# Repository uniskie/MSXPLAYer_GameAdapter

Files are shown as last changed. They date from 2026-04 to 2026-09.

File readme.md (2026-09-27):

# MSXPLAYer Game cartridge Adapter  

[for English](./readme_en.md)

USB CDC（仮想COM）で MSX カセットを読み書きするツールです。（MSXPLAYer対応予定）

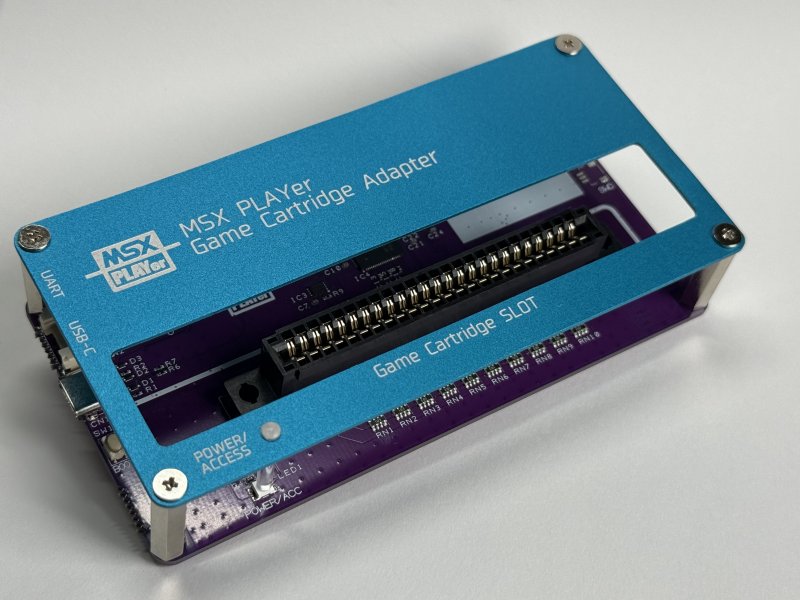
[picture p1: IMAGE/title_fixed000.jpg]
title00


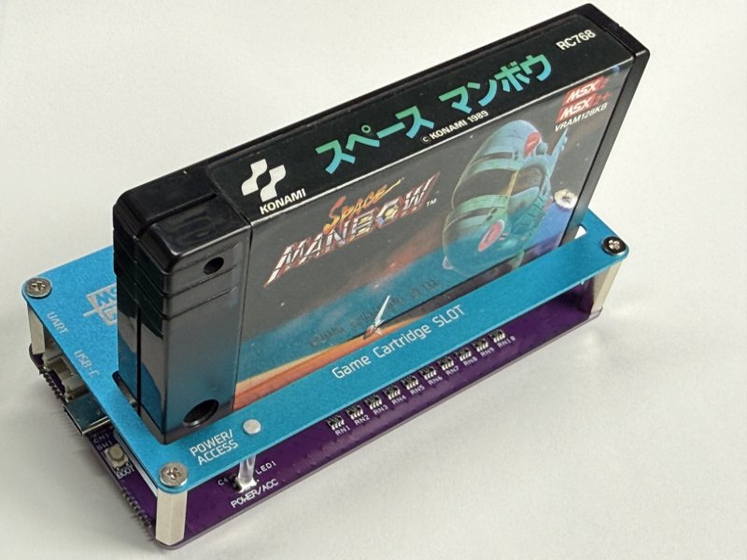
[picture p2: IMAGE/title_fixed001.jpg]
title01


## これは何？

Raspberry Pi 系マイコン（RP2350）を使った **MSX ROM カセット** を読み書きするアダプターです。  
PC から **USB CDC（シリアル）** 経由のコマンドを送ることで下記の事が行えます。

- ROMカセットのRead/Write
- IO Read/Write
- バッファ（64KB）への一括転送、PCへの送受信
- Buffer上の簡易スクリプトによる一括でのスロットアクセス

## 特徴

- **USB CDC（仮想COM）** でコマンド操作（原則ドライバー不要 Windows / Linux / macOS で利用可能）  
- **スロット電源制御・過電流検知機能**を搭載  
- カセットの**メモリおよびIO空間に対するRead/Write**をサポート  
- **クロック信号**をサポート  

- **IO電圧5V対応**
- **ユーザ側での**ファームウェアアップデート可能
- **デュアルコア構成**を活用した低レーテンシー設計  
  - Core0: USB受信・コマンド解析・送信キュー吐き出し  
  - Core1: コマンド実行（GPIOアクセス等）
- **コマンドQueue機能** によりコマンド連続
- **簡易スクリプト**搭載（簡易VM）  

（以下は当方からの頒布品に関して）

- 信頼性が必要なスロットコネクタに **大手メーカ製(AMP/ヒロセ)** 部品を採用

## 実機スロットとの違いについて

実機と異なり下記機能をサポートしていません。  

- +12V/-12Vの電源供給  
- サウンド出力  
- DRAM Refresh信号のサポート  
- M1信号のサポート

## 本体説明

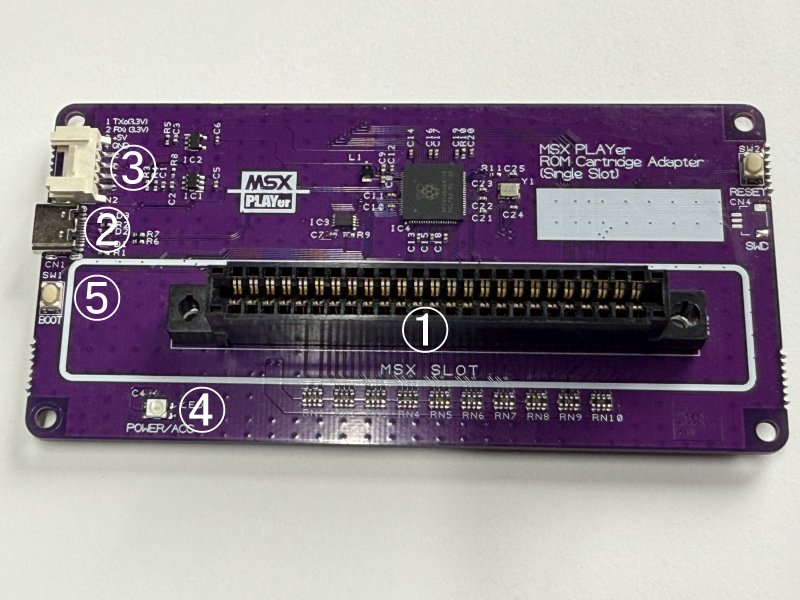
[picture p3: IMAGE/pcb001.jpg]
pcb001


1. MSX SLOT: MSX規格のカセットが挿入します。  
2. USB-C端子: PC本体との接続端子です。  
3. GROVE端子: GROVE仕様の通信端子です。信号の電圧レベルは3.3Vです。現状はデバッグ用のUART信号が出ています。  
4. ACCESS LED: カセットのアクセス状況を示すLEDです。電源供給時およびカセットアクセス時に点灯します。
5. BOOTスイッチ：通常は使用しません。

## [重要] MSXPLAYer対応について

MSXPLAYerの対応は現在、MSX Associationにて進めています。  
当方からの頒布版については、MSXPLAYerが付属予定ですが現段階では未定です。

当面の間は、EarlyAccess版になり、MSXPLAYerを既に持っており、動作チェックに協力いただける、Tester向けの頒布になります。

その為、MSXPLAYerの入手に下記書籍が必要になります。  

**「MSX-BASICでゲームを作ろう　懐かしくて新しいMSXで大人になった今ならわかる」**  
<https://www.amazon.co.jp/dp/4297148900/>
<https://books.rakuten.co.jp/rb/18203653/>  
<https://www.yodobashi.com/product/100000009004112958/>  

こちらで入手したMSXPLAYerにパッチを当てる形で対応を予定しています。  
MSXPLAYer側の不具合発生時の報告用のフォームなども準備中です。  

具体的な対応版入手方法については配布が開始してから追記します。

## OpenMSXなど他プラットフォームの対応について

協力いただける方募集中です。XのDMでご相談いただけると嬉しいです。  

## 頒布について

現在はEarly Access版になります。  
これは、動作チェックや対応ソフトの開発に協力いただける、Tester向けの頒布になります。  
MSXPLAYerは、別途必要になること、将来の正式頒布版と仕様が異なることをご了承できる方のみ購入ください。  

完成させるのには、ドライバーを使った簡単な組み立て作業が必要です。  
コネクターキット版については、スロット部分の簡単な半田付け作業が必要になります。  

### 頒布サイト

スロットが半田付けが必要な半田付けキット版と基板完成版の2種類が用意されます。  
価格については、製造時の世界状況によりしばらくの間大きく変動する可能性が高いです。ご了承ください。  

#### Booth

※2026/5/10 12:00(JPT)～  
<https://ifc.booth.pm/items/8175544>

基板完成版：￥7,060 / 半田付けキット版￥6,560

## 内容物一覧

1. Game cartridge Adapter 基板  
2. 専用アルミパネル  
3. ゴム足
4. スペーサー x 4  
5. ネジ(φ3 x 8mm) x 8  
6. LEDライトパイプ  
7. 50ピンカードエッジコネクタ（半田付けキット版のみ）

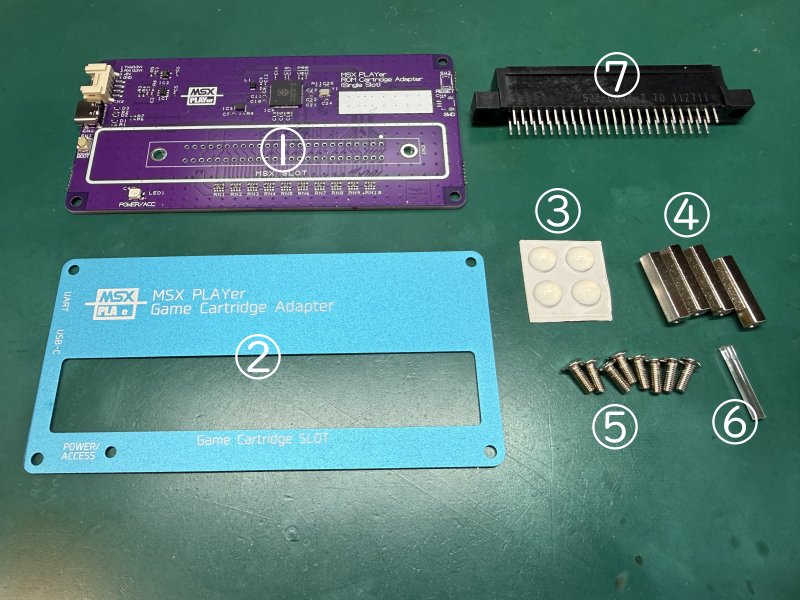
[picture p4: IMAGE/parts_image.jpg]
PARTS


## 組み立て方法

### 1.カードエッジコネクタの半田付け (半田付けキット版のみ)

カードエッジコネクタを半田付けします。コネクタには方向はありません。  
取り付けの際は、基板との隙間が空かない様に注意してください。  
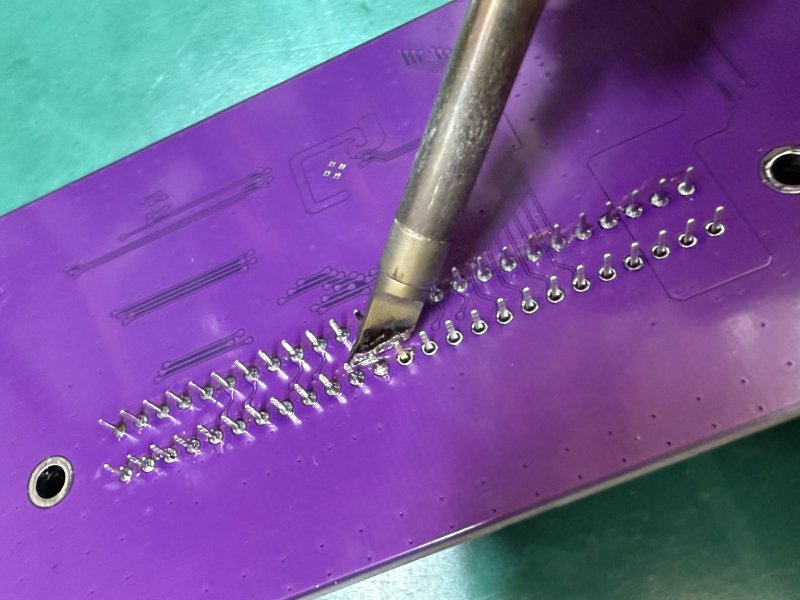
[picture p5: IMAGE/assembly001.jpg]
assembly1


始めに両端の端子を半田付けして浮きが無いか確認してから他の端子を半田付けをすると、確実だと思います。  
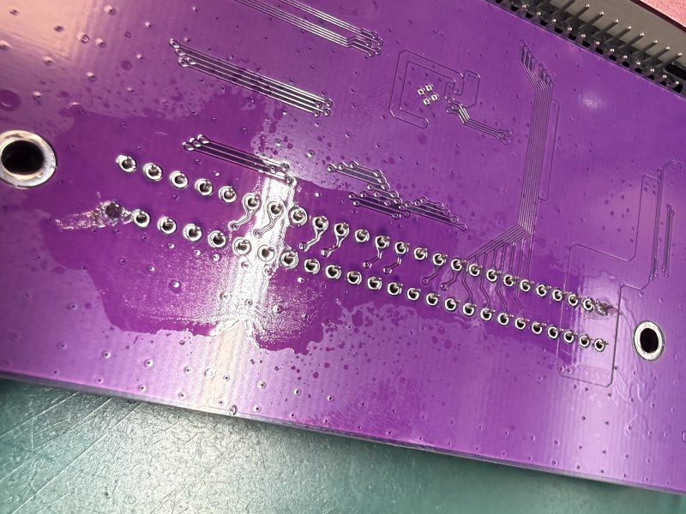
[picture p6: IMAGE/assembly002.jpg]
assembly2


付属のコネクタがヒロセ製の場合、そのままでは少し足が長いので余分な部分はニッパーを使いカットします。  
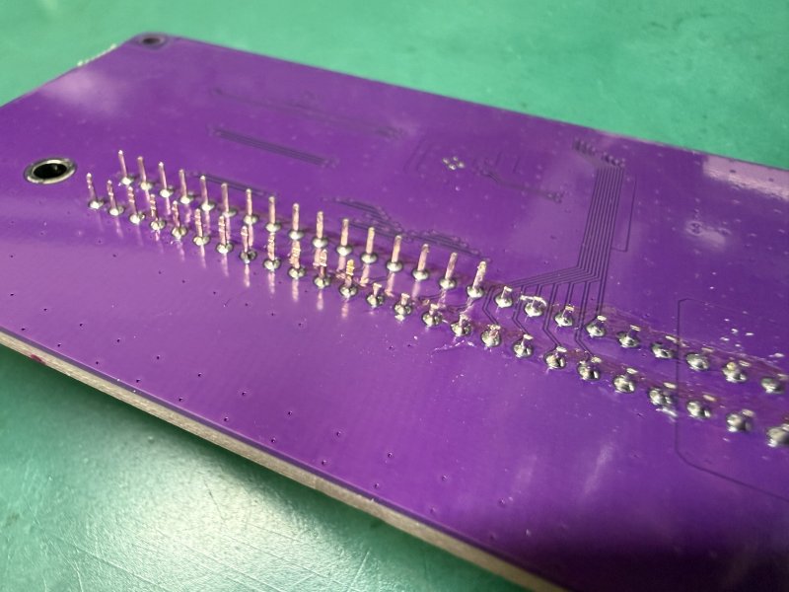
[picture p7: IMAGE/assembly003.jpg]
assembly3


### 2.ライトパイプの取り付け

パネルにライトパイプを押し込みます。平らな面を先にしパネル表面から当該パーツを挿入し、隙間が無くなるまで押し込みます。  
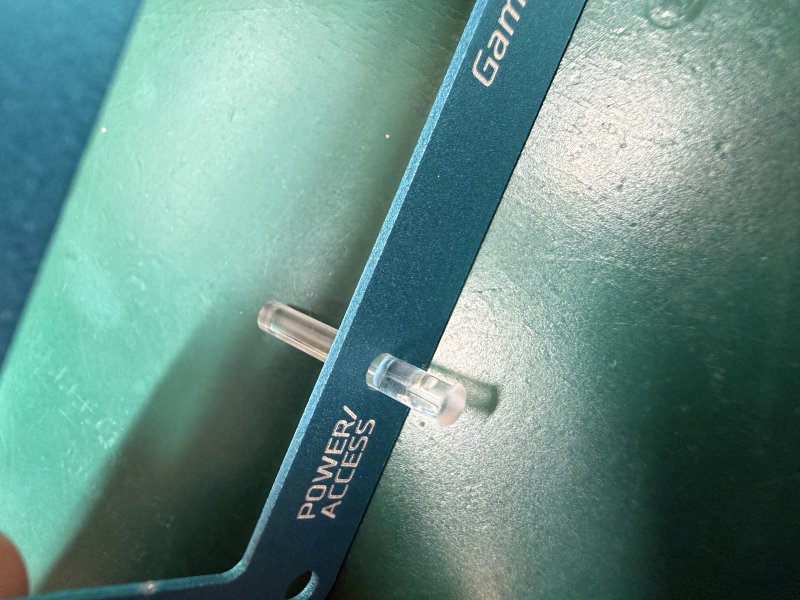
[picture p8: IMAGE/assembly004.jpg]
assembly4

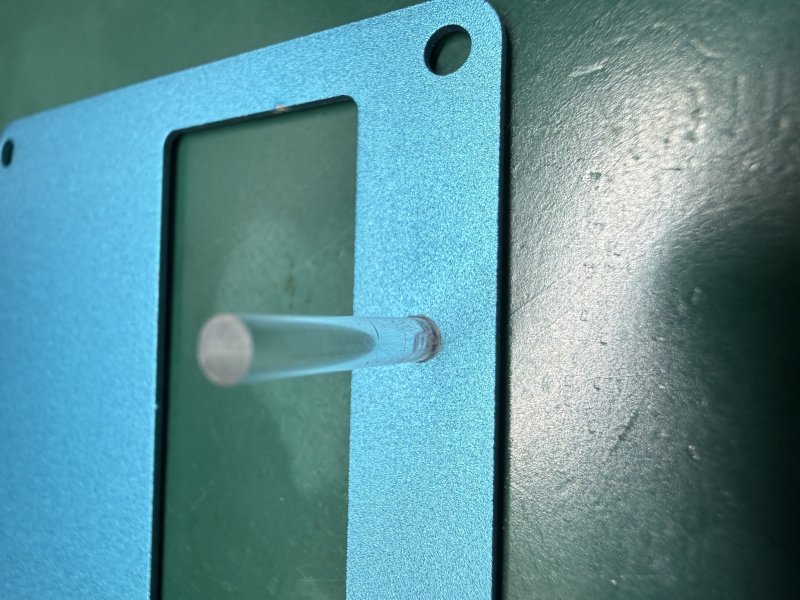
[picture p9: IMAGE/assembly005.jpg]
assembly5


### 3.スペーサーの取り付け(表)

パネル表側をネジ止めしてスペーサを取り付けます。  
最後に微調整をするので、このときは軽く締める程度にして置く方が良いです。  
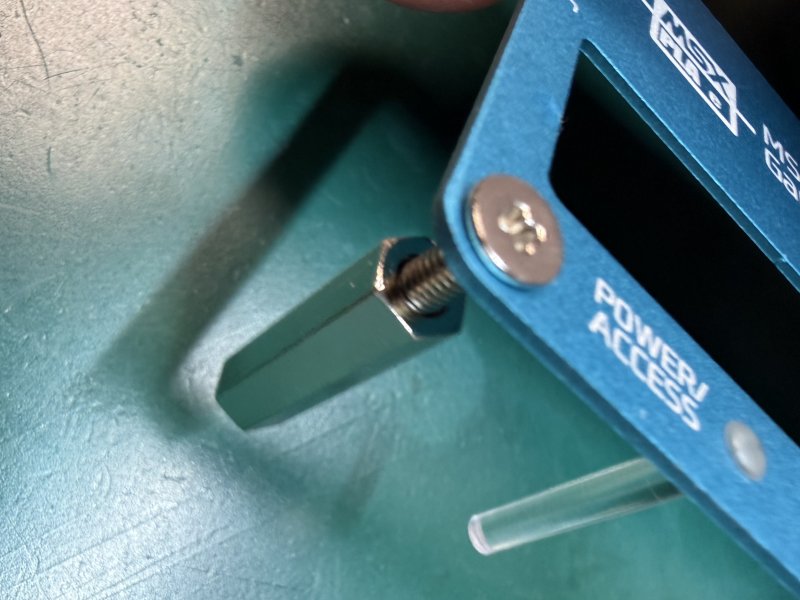
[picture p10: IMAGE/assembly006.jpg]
assembly6


### 4.スペーサーの取り付け(裏)

スペーサの上に基板を載せネジ止めします。基板の向きに注意してください。
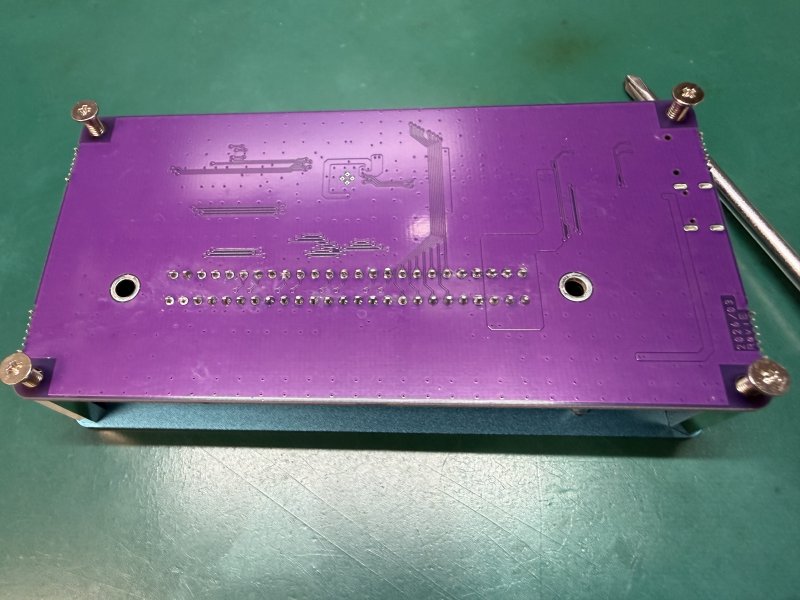
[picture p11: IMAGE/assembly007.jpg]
assembly7

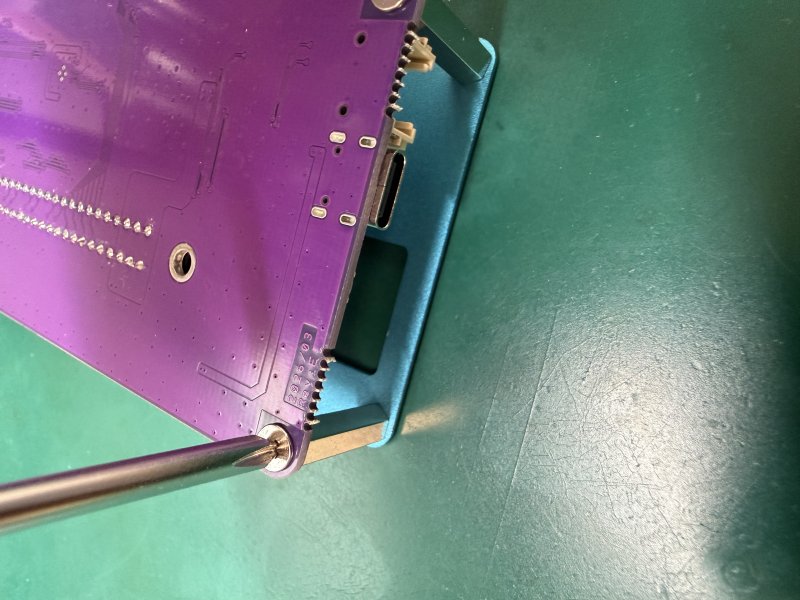
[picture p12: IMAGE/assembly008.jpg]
assembly8


裏面ネジを4本を締めおわったら、表のネジ4本についても本締めしてください。  
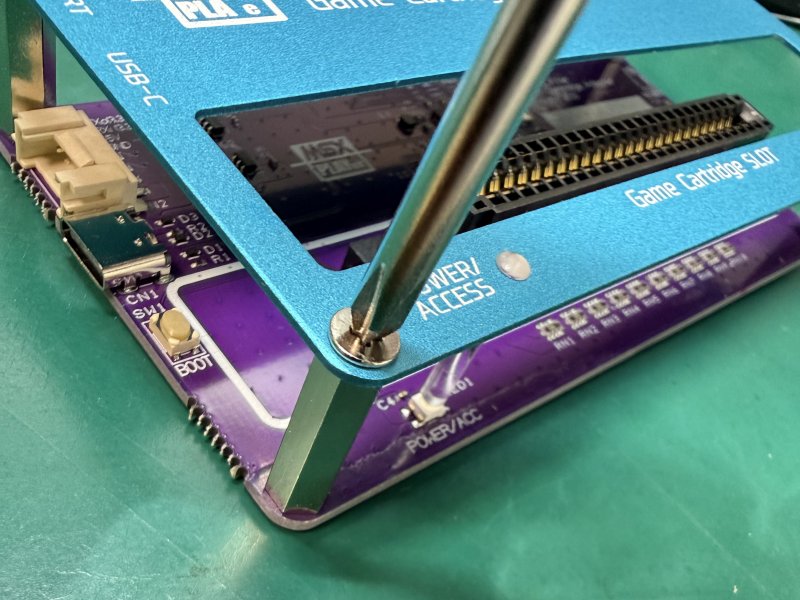
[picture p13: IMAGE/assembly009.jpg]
assembly9


### 5.ゴム足の貼り付け

裏面の基板、ネジ近辺の4カ所にゴム足を貼り付けます。  
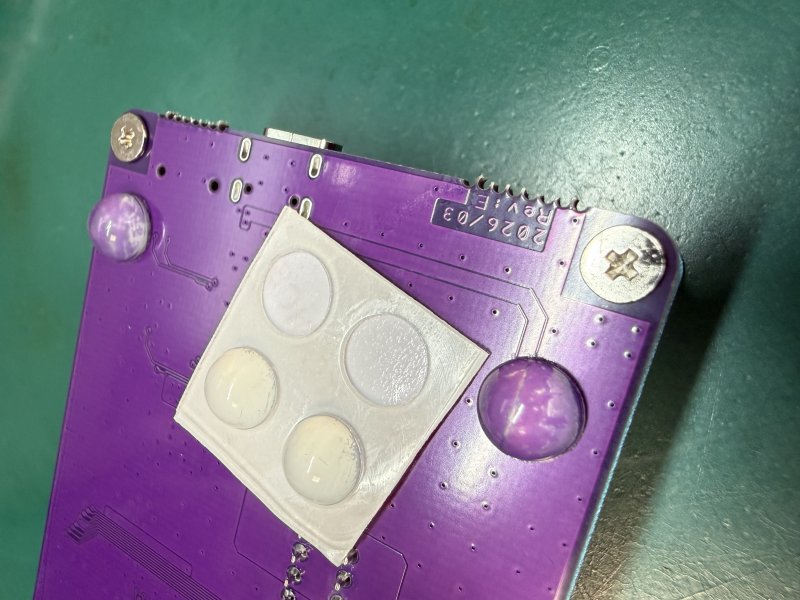
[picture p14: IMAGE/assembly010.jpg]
assembly10


これにてすべての作業が完了です。お疲れ様でした。  

## 動作チェック (Windows向け)  

下記ファイルをダウンロードの上、MSXのカセットを本機に挿して、プログラムを実行してください。  
正常に動作した場合は、下記の様にカセットの0x4000から内容が表示されます。  

**動作チェックプログラム** [MSXPLAYer Game Cassette Adapter動作確認プログラム](./SOFTWARE/TestProgram/)  

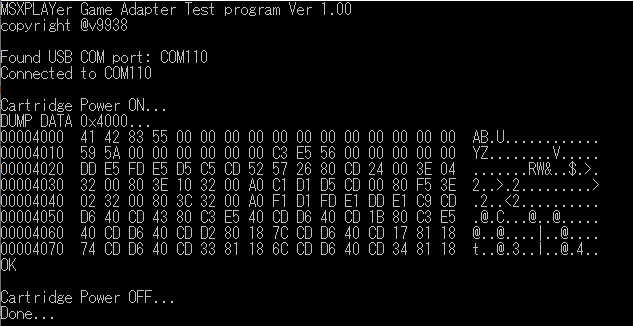
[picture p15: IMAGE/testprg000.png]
動作チェック画面


---

## 技術資料

### USB CDC コマンド仕様

[MSXPLAYer Game Cassette Adapterコマンド仕様](./com_command.md)  

### サンプルプログラム  

Windows向け：(VC++2019/2026で動作確認済)  

- **Game Cartridgeダンプサンプル(要 FW:260531以上):**  [ROMカセットDUMPプログラム](./SOFTWARE/MSXCR_ROMDUMPER_FW260531/)
- **Game Cartridgeダンプサンプル(要 FW:260520以上):**  [ROMカセットDUMPプログラム](./SOFTWARE/MSXCR_ROMDUMPER_FW260519/)
- **Game Cartridgeダンプサンプル:**  [ROMカセットDUMPプログラム](./SOFTWARE/MSXCR_ROMDUMPER/)
- **Script Engineサンプル:** [MSX_SimpleCartridge書き込みプログラム](./SOFTWARE/SimpleROM64KWriter/)  
　　対応cartridge:[https://github.com/v9938/MSX_SimpleCartridge](https://github.com/v9938/MSX_SimpleCartridge)  

### その他プログラム  

- **Litheliaさん作成 MSX-PLAYer-GCA-Reader:**  [https://github.com/Lithelia/MSX-PLAYer-GCA-Reader](https://github.com/Lithelia/MSX-PLAYer-GCA-Reader)  
- **madscientさん作成 mgadump:**  [https://github.com/madscient/mgadump](https://github.com/madscient/mgadump)  
- **t-bucchiさん作成 MSXPLAYer Game Cartidge Adapter GUI:**  [https://github.com/t-bucchi/msx-cartrigde-adapter-gui](https://github.com/t-bucchi/msx-cartrigde-adapter-gui)  

### MSXCR_ROMDUMPER_FW260531 の使い方

本プログラムは FW 260520 以降で追加された `SMTH` コマンドを利用して、
ROM 読み出し時の HASH 値を取得しながらダンプを行う Windows 用ツールです。  
260531版では、バンク処理などを見直して、高速化と動作安定化を図りました。  

#### コマンドライン

- 出力ファイル名を指定する通常モード

  ```bat
  MSXCR_ROMDUMPER.exe dump.rom
  ```

- 出力先ディレクトリを指定する自動ファイル名モード

  ```bat
  MSXCR_ROMDUMPER.exe /AUTO
  ```

  または

  ```bat
  MSXCR_ROMDUMPER.exe /AUTO .\OUT
  ```

#### 各モードの説明

**通常モード**
コマンドライン引数に指定したファイル名で保存します。

**自動ファイル名モード(/AUTO)**
ROM 情報および HASH 値をもとに保存ファイル名を自動決定します。  
第2引数を指定した場合は、そのフォルダーに保存します。  
第2引数を省略した場合はカレントフォルダーに保存します。  

#### msxromdb.xml/softwaredb.xml について

本ソフトは、BlueMSX/OpenMSXのROM Databaseを利用した自動照合を行います。  
'softwaredb.xml' または'msxromdb.xml' のファイル名で実行ファイルと同じフォルダーに配置してください。  
本ファイルが存在する場合、ROM DB 情報を使った名称判定・ファイル名決定に利用されます。  

XML形式のROM DatabaseはBlueMSXのインストールディレクトリーまたは、下記から入手可能です。[https://romdb.vampier.net/downloads.php](https://romdb.vampier.net/downloads.php)  

#### 出力ファイル名について

**通常モード**では、指定したファイル名そのままで保存されます。  
**自動ファイル名モード**では、ROM の判定結果に応じた名前で保存されます。  
`softwaredb.xml`/`msxromdb.xml` が利用できる場合は、ROM DB に登録された情報を優先してファイル名を決定します。  
ROM DB が使えない場合や一致情報が得られない場合は、ROM サイズや HASH 値などを元にした自動生成名になります。  
保存先に同名の既存ファイルがある場合は、そのファイルの内容を読み出して比較します。  
既存ファイルの内容が同一であれば、ファイル名の先頭に `[same_+hash]` を付与します。  
既存ファイルの内容が異なる場合は、ファイル名の先頭に `[other_+hash]` を付与します。  
読み取りに失敗したと推測される場合は、ファイル名の先頭に `[unsuccessful]` を付与します。  

## 動作確認済ROMカセット

[動作確認済ROMカセットリスト](./softlist.md)  

## ファームウェアについて

- Firmware Version: **2.10**
- PCB REV_B2 / REV_Fを起動時に自動判別します。
- USB CDCにはTinyUSB 0.21.0とローカル復旧パッチを使用しています。

下記フォルダーにコンパイル済のファームを置いてあります。  

[ファームウェア置き場](./FIRMWARE/UF2)

## ファームウェアアップデートについて

2種類の方法があります。

- BOOTスイッチを使う方法
BOOTスイッチを押しながら、USBケーブルを挿入してBOOTモードにします。
RP2350の名称のドライブが現れるので上記ファイルをCOPYしてください。  

- Firmware Update用ツールを使う方法  
FFU支援ツールとして`msxcr_ffu.exe`を提供しています。  
上記FFUフォルダーに置いてあるバッチファイル`ffu.bat`を実行するとFirmwareがUpdateされます。  

### ファイル構成（概要）

- `main.c`
  - USB CDC受信（行バッファ → パース）
  - コマンドキュー（Core0→Core1）
  - Slot Memory / IO の Read/Write
  - BRCV受信（バイナリ受信モード）
  - BSND送信（バイナリ送信キュー）
  - LED制御（WS2812）
  - Factory Test（GPIOテスト）
  - Script Engine（executeCommands）
- `commands.c / commands.h`
  - コマンド名 → 実行関数（cmd_*）のテーブル（公開コマンド一覧）
- `ports.c / ports.h`
  - GPIO 定義（`board_pins[]`）
- `ws2812.pio`
  - WS2812制御用PIOプログラム(from SDK pico-examples)
- `pwm_low_hiz.pio`
  - Slot Clock用PIO（LOW→Hi-Z）
- `usb_descriptors.c / tusb_config.h`
  - USB CDCのdescriptor/buffer設定

### ファームウェア動作概要（データフロー）

1. PCからUSB CDCでテキストコマンド送信（例: `SMRD,1000\r\n`）
2. Core0が改行まで `lineBuf` に蓄積し、パースして `commandBufs[]` に投入
3. Core1が `cmd_table[]` から該当関数を探し `cmd_*()` を実行
4. 応答は `cdc_queue[]` に積まれ、Core0の `cdc_task()` がUSBへ送信

### ビルド

Visual Studio CodeのPIC-SDK2.20環境でコンパイルしています。  

## USB VID/PIDについて

MSXライセンスコーポレションの許諾の元 旧ASCII社のVIDとPIDの割り当てを受け使用しています。  
本製品を改変したものを製作する場合は、別のVID/PIDを使用する様にしてください。  

## 回路図  

[回路図 PDF](./PCB/MSXPLAYerCR_1SLOT_RevD.pdf)
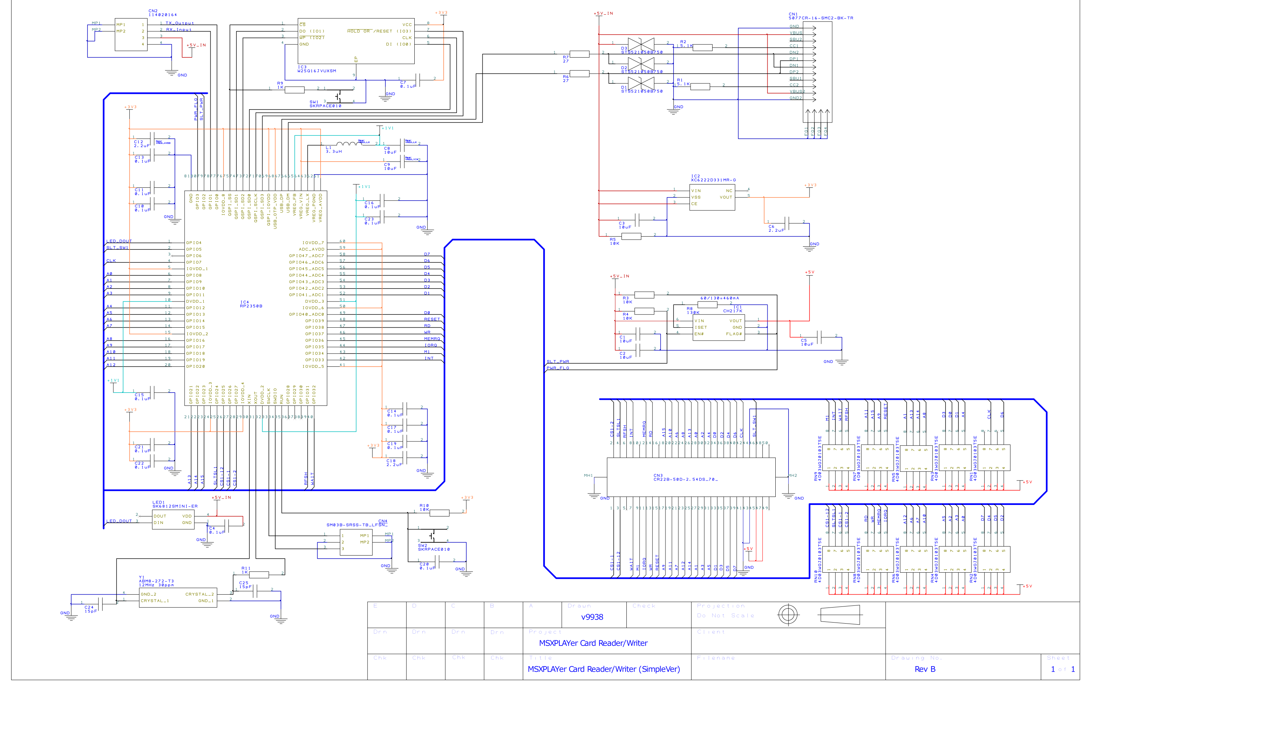
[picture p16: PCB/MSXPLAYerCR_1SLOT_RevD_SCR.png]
回路図


## PCBデータ

[Rev D ガーバデータ](./PCB/GARBER_DATA/)

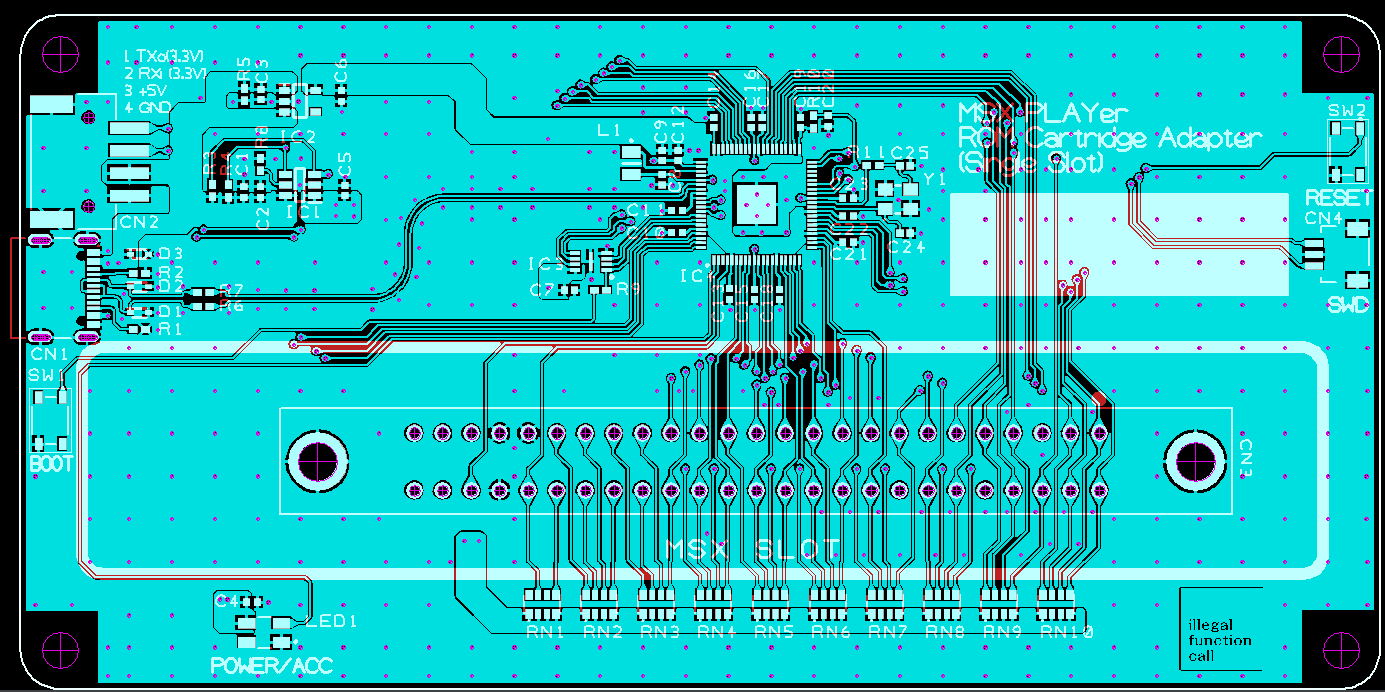
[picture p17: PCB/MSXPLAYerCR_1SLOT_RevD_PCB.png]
PCBイメージ


## BOM List

[Rev D PCBパーツリスト](./PCB/partslist_RevD.md)

## パネル  

[アルミパネルデータ](./PCB/PANEL_DATA/)

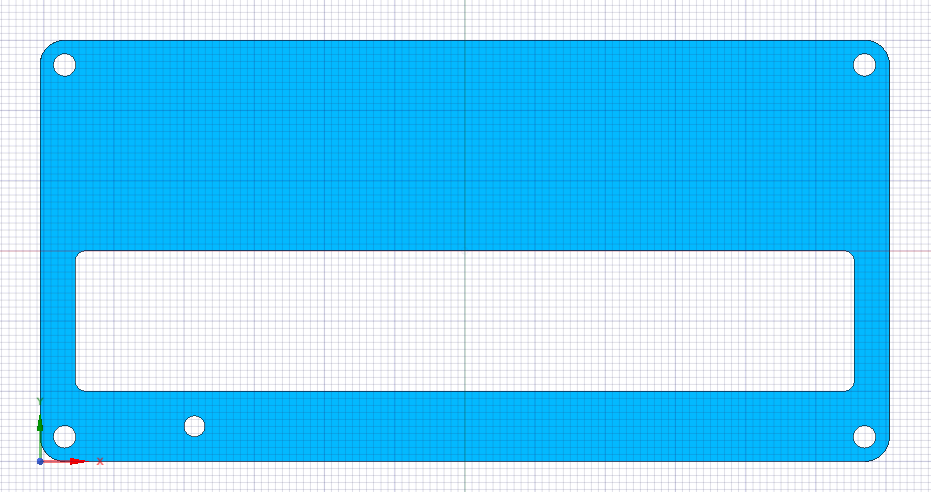
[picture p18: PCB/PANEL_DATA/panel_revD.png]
パネルイメージ


組み立てには、別途下記のパーツが必要です。  

|パーツ名|個数|入手先|
|---|---|---|
|φ3mm x 8mm ネジ|8|<https://www.hirosugi-net.co.jp/shop/g/g104024/>|
|φ3mm x 20mm スペーサー|4|<https://www.hirosugi-net.co.jp/shop/g/g670/>|
|ライトパイプ(VCC LFB075CTP)|1|<https://www.digikey.jp/ja/products/detail/visual-communications-company-vcc/LFB075CTP/5723594>|

## MSXPLAYerの名称／ロゴについて  

MSX および MSXPLAYerはMSXライセンスコーポレションの登録商標です。  

当方の頒布品につけているMSXPLAYerロゴについては、MSXアソシエーションとの開発協力下で当商品への使用が許諾されています。

## ライセンス

このプロジェクトはMIT ライセンスにて公開しています。

なお、コードの一部にRaspberryPiのpico-sdk v2.20よりコピーしたものを含みます。  
当該部分についてはBSD 3-Clause "New" or "Revised" Licenseが定める要件により、Raspberry Pi (Trading) Ltd.よりライセンスされたものです。

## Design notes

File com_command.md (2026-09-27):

# MSXPLAYer Game Cassette Adapterコマンド仕様  

## 共通仕様

- 1行 = 1コマンド（`,`区切り）
- フォーマット（最大4引数）:

  ```CMD
  CMD[,ARG1[,ARG2[,ARG3[,ARG4]]]]<CR|LF|CRLF|LFCR>
  ```

- コマンド名は大文字小文字を区別しません（内部で大文字化）
- 引数は基本 **16進数**（`0x` プレフィクス可）
- 未指定引数は、デフォルト動作になります。
- 戻り値:
  - 通常は処理結果として最後に `OK` / `FAIL` を返します
  - `ERROFF` 中は OK/FAIL 表示を抑止し、成功/失敗カウントのみ更新します

## コマンド一覧（仕様書形式・実装準拠）

### 1) HSET - Hardware Setting

- **機能**: ハードウェアアクセス時の待ち時間や互換モードを設定する
- **書式**: `HSET,[Address],[Data]`
- **引数**:
  - `Address` : 設定項目番号（16進）
  - `Data` : 設定値（16進、省略時は初期値に戻す）
- **応答**: `OK` / `FAIL`
- **備考**:
  - 現在のファームでは下記設定に対応しています。

| Address | 設定項目 | 内容 | 初期値 |
|---|---|---|---|
| `0` | `MEMWAIT` | Memory Read/Write後のWait時間 (`n x 10ns`) | `0` |
| `1` | `RDWAIT` | Memory Read時の/RD信号幅 (`n x 10ns`) | `100` |
| `2` | `WRWAIT` | Memory Write時の/WR信号幅 (`n x 10ns`) | `18` |
| `3` | `P6MODE` | PC-6001 16KB mode設定 (`0`:OFF / `1`以上:ON) | `0` |

- **設定例**:
  - `HSET,1,64` : RDWAIT を `1000ns=1us` に設定
  - `HSET,1` : RDWAIT を初期値に戻す

- **補足**:
  - 設定値は `HINF` コマンドで確認できます。
  - `HINF` の出力には `MEMWAIT` / `RDWAIT` / `WRWAIT` / `P6MODDE` が表示されます。
  - 未対応の `Address` を指定した場合は `FAIL` になります。

---

### 2) ERROFF - Result display OFF

- **機能**: コマンド実行結果の逐次表示（OK/FAIL表示）を抑止する
- **書式**: `ERROFF`
- **引数**: なし
- **応答**: `OK`
- **備考**:
  - 有効時は `passCount/errCount` で統計を蓄積
  - 大量処理（転送・スクリプト）時のログ抑制に利用

---

### 3) ERRON - Result display ON + summary

- **機能**: `ERROFF` を解除し、抑止期間の集計を表示する
- **書式**: `ERRON`
- **引数**: なし
- **応答**:
  - `PASS : <passCount>`
  - `FAIL : <errCount>`
  - その後、失敗があれば `FAIL`、なければ `OK`
- **備考**:
  - `FAIL` があった場合は `ERRON` 自体が `FAIL` で返る仕様

---

### 4) BCLR - Buffer Clear（slotMem 初期化）

- **機能**: 内部バッファ（64KB）を指定値で埋める
- **書式**: `BCLR(,[BufferAddress],[Length],[Data])`
- **引数**:
  - `BufferAddress` : 開始位置（省略時 0）
  - `Length` : 長さ（省略時 64KB相当）
  - `Data` : 埋め値（省略時 `0xFF`）
- **応答**: `OK` / `FAIL`
- **備考**:
  - 範囲外指定は `FAIL`
  - 長さはバッファ境界に合わせて補正される場合がある

---

### 5) BSND - Buffer Send Host（Device→Host バイナリ送信）

- **機能**: 内部バッファのデータをPCへ送信する（バイナリ）
- **書式**: `BSND,[BufferAddress],[Length]`
- **引数**:
  - `BufferAddress` : 送信開始位置
  - `Length` : 送信バイト数
- **応答**:
  - バイナリデータがPCに送信されます。
  - その後に `OK/FAIL`（displayFlag=true時）が送信されます。
- **備考**:

---

### 6) BRCV - Buffer Receive Host（Host → Device バイナリ受信）

- **機能**: PCから指定長のバイナリを受信し、`slotMem[]` に格納する
- **書式**: `BRCV,[BufferAddress],[Length]` +（続けて Length バイトのバイナリ本体）
- **引数**:
  - `BufferAddress` : 格納開始位置
  - `Length` : 受信バイト数
- **応答**:
  - 受信完了後に `OK/FAIL`
- **備考**:
  - `BRCV` 実行後直後はバイナリ受信モードへ移行します
  - 範囲外（`BufferAddress + Length` が64KB超）などは `FAIL`
  - コマンド終端には `CR` / `LF` / `CRLF` / `LFCR` を使用できます。

---

### 7) HVER - Hardware Version

- **機能**: ハードウェア名、PCBリビジョン、ファームウェアバージョンを表示
- **書式**: `HVER`
- **引数**: なし
- **応答**:
  - `HARDWARE NAME : <Hardware Name>`
  - `HARDWARE VER : <REV_B2|REV_F|UNKNOWN>`
  - `FIRMWARE VER : <Firmware Version>`
  - `OK`
- **備考**:
  - PCB REV_B2/REV_Fは起動時に自動判別します。
  - 判定できない場合は`UNKNOWN`を表示します。
  ※ 260531(V1.40)で出力フォーマットが変更になっています。  

---

### 8) HINF - Hardware Information

- **機能**: ハード構成情報の表示
- **書式**: `HINF`
- **引数**: なし
- **応答**: 各種 `KEY,VALUE` 行 + `OK`
- **備考**:
  - `SLOTNUM`: Readerのスロット数  
    Readerについている物理スロット数を表します(1～4)
  - `SLOTPHY`: Readerの物理スロット配置情報  
    Readerについている物理スロットの配置を示します。(1が有効)

    |bit7-4|bit3|bit2|bit1|bit0|
    |---|---|---|---|---|
    |0000|SLOT3|SLOT2|SLOT1|SLOT0|

    例：SLOTNUM:1 / SLOTPHY:2 = 付いているスロット1つでSLOT1扱い  

  - `POWERCTRL`: 電源制御有無  
    カセットに対する電源制御の有無を示します。(1で有り)  
  - `CURRENTSENSOR`: 過電流制御有無  
    カセットに対する過電流検知回路の有無を示します。(1で有り)  
  - `PWR12V`: +12V/-12V電源の有無  
    カセットに対する+12V/-12Vの有無を示します。(1で有り)  
  - `SLOTCLOCK`: 外部スロットクロックの有無  
    カセットに対する精密な3.58MHzのクロック供給回路の有無を示します。(1で有り)  
  - `LINEOUT`: 音声LineOut有無  
    カセットのSOUND端子の出力回路の有無を示します。(1で有り)  
  - `PSGUNIT`: PSG ユニット有無  
    ReaderにPSG音源相当相当の機能があるか示します。(1で有り)  
  - `LFCR`: 改行コードの設定値  
    入力されているCOMMAND文字列の改行コードの種別を表示しています。(1は、"\n" = 0x0d,0x0a 扱い)  
  - `COMDBG`: UARTからのデバッグ出力設定値  
    1の時はUARTからデバッグ用の出力が出る設定です。  
  - `SCRLOOP`: ScriptモードのLOOP回数の最大設定値  
    ScriptモードのLOOP回数を表示します。初期値は1000回  
  - `MEMWAIT`: Read/Write後のWait値  
    Memory Read/Write後のWait時間 初期値は0  
  - `RDWAIT`: Memory Read時の/RD幅  
    Memory Readの/RDがLOWになっている時間の設定値 初期値は10 (180ns)  
  - `WRWAIT`: Memory Write時の/WR幅  
    Memory Writeの/WRがLOWになっている時間の設定値 初期値は10 (180ns)  
  - `P6MODE`: PC6001カセットモードの設定値  
    PC6001 16K Read Modeの設定値表示  

---

### 9) HSTS - Hardware Internal Status

- **機能**: 内部状態（主にキュー残数・エラー有無）の表示
- **書式**: `HSTS`
- **引数**: なし
- **応答**:
  - キュー残数相当（`count-1`）を1行表示
  - `OK/FAIL`
- **備考**:
  - 実行したキューにエラーが発生した場合は`FAIL`になります。  

---

### 10) SCHK - Slot Cassette Check

- **機能**: スロット接続状態を表示（Power ON不要）
- **書式**: `SCHK`
- **引数**: なし
- **応答**: `0000/0010/0100/0110` のいずれか + `OK`
- **備考**: 応答値はSLOT3210の順番の文字列です。カセットがさしてあるスロットが1になります。  

---

### 11) SPON - Slot Power ON

- **機能**: スロット電源投入、クロック有効化、RESET制御等の初期化
- **書式**: `SPON`
- **引数**: なし
- **応答**: `OK/FAIL`
- **備考**:
  - 過電流発生時は `FAIL`になります。  

---

### 12) SPOFF - Slot Power OFF

- **機能**: スロット電源断、信号を安全状態へ戻す
- **書式**: `SPOFF`
- **引数**: なし
- **応答**: `OK/FAIL`
- **備考**:

---

### 13) SRST - Slot Reset

- **機能**: スロットRESET信号をトグルしてリセットする
- **書式**: `SRST`
- **引数**: なし
- **応答**: `OK`

---

### 14) SSEL - Slot Select

- **機能**: デフォルトスロット番号を設定
- **書式**: `SSEL,[Slot]`
- **引数**:
  - `Slot` : `1` または `2`
- **応答**: `OK/FAIL`
- **備考**:
  - `Slot` 未指定は `FAIL`
  - 以後、Slot省略時にこの値が使われる

---

### 15) SMRD - Slot Memory Read（1 byte）

- **機能**: スロットメモリから1バイト読み出す
- **書式**: `SMRD,[Address](,[Slot])`
- **引数**:
  - `Address` : 0000〜FFFF　スロットメモリアドレス
  - `Slot` : 1 or 2（省略時はdefaultSlot）
- **応答**:
  - `<addr> : <data>`（例 `1000 : 3F`）+ `OK/FAIL`

---

### 16) SMWR - Slot Memory Write（1 byte）

- **機能**: スロットメモリへ1バイト書き込む
- **書式**: `SMWR,[Address],[Data](,[Slot])`
- **引数**:
  - `Address` : 0000〜FFFF　スロットメモリアドレス  
  - `Data` : 00〜FF　書き込みデータ  
  - `Slot` : 1 or 2（省略時defaultSlot）
- **応答**: `OK/FAIL`

---

### 17) SMTR - Slot → Buffer Transfer Read（一括Read）

- **機能**: スロットからバッファーへ連続読み出し
- **書式**: `SMTR,[Address](,[Length],[BufferAddress],[Slot])`
- **引数**:
  - `Address` : 0000〜FFFF　スロット側開始アドレス
  - `Length` :  0000〜FFFF　読み込み長（省略時最大）
  - `BufferAddress` :  0000〜FFFF　バッファー格納開始位置（省略時0）
  - `Slot` : 1 or 2（省略時defaultSlot）
- **応答**: Data + `OK/FAIL`

---

### 18) SMTW - Buffer → Slot Transfer Write（一括Write）

- **機能**: バッファーからスロットへ連続書き込み
- **書式**: `SMTW,[Address],[Length],[BufferAddress](,[Slot])`
- **引数**:
  - `Address` :  0000〜FFFF　スロット側開始アドレス
  - `Length` :  0000〜FFFF　書き込み長
  - `BufferAddress` : バッファー 読み出し開始位置
  - `Slot` : 1 or 2（省略時defaultSlot）
- **応答**: `OK/FAIL`

---

### 19) IORD - IO Read（1 byte）

- **機能**: IOポートから1バイト読み出す
- **書式**: `IORD,[IO]`
- **引数**:
  - `IO` :  0000〜FFFF　IOアドレス（16bit扱い）
- **応答**:
  - `<io> : <data>` + `OK/FAIL`

---

### 20) IOWR - IO Write（1 byte）

- **機能**: IOポートへ1バイト書き込む
- **書式**: `IOWR,[IO],[Data]`
- **引数**:
  - `IO` :  0000〜FFFF　IOアドレス  
  - `Data` : 00〜FF　書き込みデータ  
- **応答**: `OK/FAIL`

---

### 21) IOTR - IO → Buffer Transfer Read（実装準拠）

- **機能**: IOから連続読み出ししてバッファーへ格納
- **書式**: `IOTR,[IO],[Length],[BufferAddress](,[Mode])`
- **引数（実装準拠）**:
  - `IO` : 0000〜FFFF　開始IOアドレス
  - `Length` :0000〜FFFF　読み出し回数（バイト数）
  - `BufferAddress` : バッファー格納開始位置
  - `Mode` : 1 でIOアドレスはアクセス毎に加算、省略時は同一アドレスにアクセス (機能追加：V1.41～)
- **応答**: `OK/FAIL`

---

### 22) IOTW - Buffer → IO Transfer Write（実装準拠）

- **機能**: バッファーからIOへ連続書き込み
- **書式**: `IOTW,[IO],[Length],[BufferAddress](,[Mode])`
- **引数（実装準拠）**:
  - `IO` : 0000〜FFFF　開始IOアドレス
  - `Length` : 0000〜FFFF　書き込み回数（バイト数）
  - `BufferAddress` : 0000〜FFFF　バッファー読み出し開始位置
  - `Mode` : 1 でIOアドレスはアクセス毎に加算、省略時は同一アドレスにアクセス (機能追加：V1.41～)
- **応答**: `OK/FAIL`

---

### 23) BDMP - Buffer Dump（デバッグ用）

- **機能**: バッファーの内容を HEX+ASCII で表示
- **書式**: `BDMP,[BufferAddress](,[Length])`
- **引数**:
  - `BufferAddress` : 0000〜FFFF　開始位置（省略時0）
  - `Length` : 0000〜FFFF　表示長（省略時128）
- **応答**: ダンプ行 + `OK`

---

### 24) SDMP - Slot Dump（スロットメモリダンプ）

- **機能**: スロットから直接読みながらダンプ表示
- **書式**: `SDMP,[Address](,[Length],[Slot])`
- **引数**:
  - `Address` : 0000〜FFFF　開始アドレス（省略時0）
  - `Length` : 0000〜FFFF　表示長（省略時128）
  - `Slot` : 1 or 2（省略時defaultSlot）
- **応答**: ダンプ行 + `OK/FAIL`

---

### 25) BSCR - Buffer Script Execute（スクリプト実行）

- **機能**: バッファー上のスクリプトを実行する
- **書式**: `BSCR,[BufferAddress](,[Slot])`
- **引数**:
  - `BufferAddress` :  0000〜FFFF　スクリプト先頭（省略時0）
  - `Slot` : 1 or 2（省略時defaultSlot）
- **応答**: `OK/FAIL`
- **備考**:
  - 命令形式は 4byte/命令: `[cmd][addr_hi][addr_lo][data]`
  - スクリプトの詳細は別章を参照

---

### 26) FTEST - Factory Test

- **機能**: 工場向け総合テストの実行
- **書式**: `FTEST`
- **引数**: なし
- **応答**: テストログ + `OK/FAIL`

---

### 27) LEDRDY / LEDPON / LEDACC - LED色設定

- **機能**: LED色（READY/POWER ON/SLOT ACCESS）を RGB で設定
- **書式**:
  - `LEDRDY(,[R],[G],[B])`
  - `LEDPON(,[R],[G],[B])`
  - `LEDACC(,[R],[G],[B])`
- **引数**:
  - `R` `G` `B` : 0x00〜0xFF（省略可。省略時はデフォルト値）
- **応答**: `OK`

---

### 28) SDBGON - Serial Debug Log ON

- **機能**: シリアルポートからのデバッグログ出力を有効化
- **書式**: `SDBGON`
- **引数**: なし
- **応答**: `OK`
- **備考**:
  - シリアル出力が増える分実行速度が低下します。
  - バッファーオーバーフローに注意してください。  
  - シリアルはGrove端子より出力されます。

---

### 29) _FFU - Bootloader起動

- **機能**: FFUモードへの移行、USBブートモードへ移行する
- **書式**: `_FFU`
- **引数**: なし
- **応答**: メッセージ出力後、リブート（以降のOK/FAILは返さない）

---

### 30) LSCR - ScriptモードのLOOP回数の最大値設定

- **機能**: Scriptモードの条件成立待ちのループ回数を設定します。  
- **書式**: `LSCR(,最大LOOP回数)`
- **引数**: 0-0xFFFF (省略時は初期値の1000回)
- **応答**: `OK`

---

[260520_VERにて追加]

### 31) SMTH - Slot → Buffer Transfer Read（一括Read）+ HASH

- **機能**: スロットからバッファーへ連続読み出し+ 32bit HASHコードを計算します。  
- **書式**: `SMTH,[Address](,[Length],[BufferAddress],[Slot])`
- **引数**:
  - `Address` : 0000〜FFFF　スロット側開始アドレス
  - `Length` :  0000〜FFFF　読み込み長（省略時最大）
  - `BufferAddress` :  0000〜FFFF　バッファー格納開始位置（省略時0）
  - `Slot` : 1 or 2（省略時defaultSlot）
- **応答**: `<Length> : <HASH 32bit>`+`OK/FAIL`

---

[260531_VERにて追加]

### 32) RMSET - ROM Mapper Setting

- **機能**: RMRDコマンドで使うParameterをセットします。  
- **書式**: `RMSET,[Mapper Selector Address],[Bank Read Address],[Bank size]`
- **引数**:
  - `Mapper Selector Address]` : 0000〜FFFF　ROM Mapperの切り替えアドレス、FFFFを指定した場合は、バンク切り替えをしません。  
  - `Bank Read Address` :  0000〜FFFF　ReadするBankの先頭アドレス  
  - `Bank size` :  0000〜FFFF　1バンク辺りの容量
- **応答**: `OK/FAIL`

---

### 33) RMRD - ROM Mapper Read

- **機能**: スロットに挿してあるメガロムをバンクを切り替えながら一括で読み込みます。(バッファーは使用しません)  
- **書式**: `RMRD,[Start Bank],[Bank Capacity](,[Slot])`
- **引数**:
  - `Start Bank` : 00〜FF　スロット側開始アドレス
  - `Bank Capacity` :  00〜FF　読み込むBANK数を指定します  
  - `Slot` : 1 or 2（省略時defaultSlot）
- **応答**: Read Data + `OK/FAIL`

---

### 34) SMMR - Slot M1 Read

- **機能**: M1サイクルを使用してスロットメモリから1バイト読み出す
- **書式**: `SMMR,[Address](,[Slot])`
- **引数**:
  - `Address` : 0000〜FFFF 読み出しアドレス
  - `Slot` : 1 または 2（省略時はdefaultSlot）
- **応答**: `<Address> : <Data>` + `OK/FAIL`

---

### 35) MDMP - Slot M1 Dump

- **機能**: M1サイクルを使用してスロットメモリを読み出し、HEXおよびASCII形式で表示する
- **書式**: `MDMP,[Address](,[Length],[Slot])`
- **引数**:
  - `Address` : 0000〜FFFF 読み出し開始アドレス（省略時0000）
  - `Length` : 表示バイト数（省略時0080）
  - `Slot` : 1 または 2（省略時はdefaultSlot）
- **応答**: 16バイト単位のHEX/ASCIIダンプ + `OK/FAIL`

---

## シリアルコマンド例

### 例1: スロットの0x0000〜0x3FFFを読み出してPCへ送信

```CMD_EX1
SPON
SMTR,0000,4000,0000,01
BSND,0000,4000
SPOFF
```

### 例2: PCからバイナリを受信し、0x8000へ書き込み

```CMD_EX2
SPON
BRCV,0000,2000
(ここで 0x2000 バイトのバイナリを送信)
SMTW,8000,2000,0000,01
SPOFF
```

[260531_VERにて追加]

### 例3: ASCII8K Typeの1Mbitメガロムカセットを一括で読み込む

```CMD_EX3
SPON
RMSET,7000,8000,2000
RMRD,0,10
(ここで 0x20000 バイトのバイナリを受信)
SPOFF
```

## スクリプトモードについて

バッファーにおいたスクリプトを使うことで、PCとの通信をしないで、
データRead/Write・比較の実行を行うことが出来るモードです。  

## スクリプト形式

- スクリプト形式: [Command],[Address(2Byte)],[DATA]...  
- 1スクリプトは4バイトの固定長です。  

### スクリプトデータ フォーマット

|Address|＋0Byte|＋1Byte|＋2Byte|＋3Byte|
|---|---|---|---|---|
|**DATA**|命令コード|上位アドレス|下位アドレス|データ|

### 命令一覧

|Command|命令名|説明|
|---|---|---|
|0x00|NOP|何もしない|
|0x01|Read Memory|Slotに対してReadを実行|
|0x02|Write Memory|Slotに対してDATAを書き込む (LastDataはDATAで上書きされます)|
|0x03|Read IO|Slotに対してIOを使ったReadを実行します。(LastDataはReadしたDATAになります)|
|0x04|Write IO|Slotに対してIOを使ったWriteを実行します。(LastDataはDATAで上書きされます)|
|0x05|Wait|addressで指定したms時間待機します|
|0x06|Compare|LastDataとdataを比較します、一致したら次の命令はスキップします。|
|0x07|AND|LastData [AND] DATAを計算します、結果が0x00なら次の命令をスキップします。|
|0x08|OR|LastData [OR] DATAを計算します、結果が0x00なら次の命令をスキップします。|
|0x09|XOR|lastData [XOR] DATAを計算します、結果が0x00なら次の命令をスキップします。|
|0x0A|JMP|DATAの値だけ命令をスキップします。（0x00-7F=先命令/0x80-FF=前命令）|
|0x0B|PUSH|lastDataをaddressで指定した位置のBufferメモリに書き出します |
|0xFE|Abort|スクリプト実行を失敗で終了|
|0xFF|End|スクリプト実行を成功で終了|

※ JMP命令は、一定回数(初期値は1000回)同じ場所で実行されるとスクリプト失敗になります。  
当該値は"LSCR"コマンドで変更可能です。  

### スクリプト例

下記のコマンドで実行可能です。

```CMD_BRCV
BRCV,0,20  
(下記バイナリー送付)  
BSCR,0
```

|バイナリー値|Command|説明|
|---|---|---|
|0x02,0x55,0x55,0xaa|[Write Memory]  Address:0x5555 Data:0xaa|0x5555に0xAAの書き込み|
|0x02,0xaa,0xaa,0x55|[Write Memory]  Address:0xaaaa Data:0x55|0xAAAAに0x55の書き込み|
|0x02,0x55,0x55,0xa0|[Write Memory]  Address:0x5555 Data:0xa0|0x5555に0xA0の書き込み|
|0x02,0x40,0x00,0x41|[Write Memory]  Address:0x4000 Data:0x41|0x4000に0x41の書き込み|
|0x01,0x40,0x00,0x00|[Read Memory]  Address:0x4000|0x4000のデータを読み込む|
|0x06,0x00,0x00,0x41|[Compare]  Data:0x40|先ほど読み込んだデータと比較して0x40だったら次の命令はスキップ|
|0x0a,0x00,0x00,0xfe|[JMP] -2|2つ前の命令に戻る(つまり、0x4000が0x40になるまでループする)|
|0xff,0x00,0x00,0x00|End|スクリプト終了|

## デバッグについて

"SDBGON"コマンドを実行する事でGROVE端子(UART)より実行ログを取得できます。  
ただし、当該機能を有効にすると実行時間が遅くなりますので通常は有効にしないでください。  

シリアルポートは3.3Vレベルで配線は下記の様になっています。  
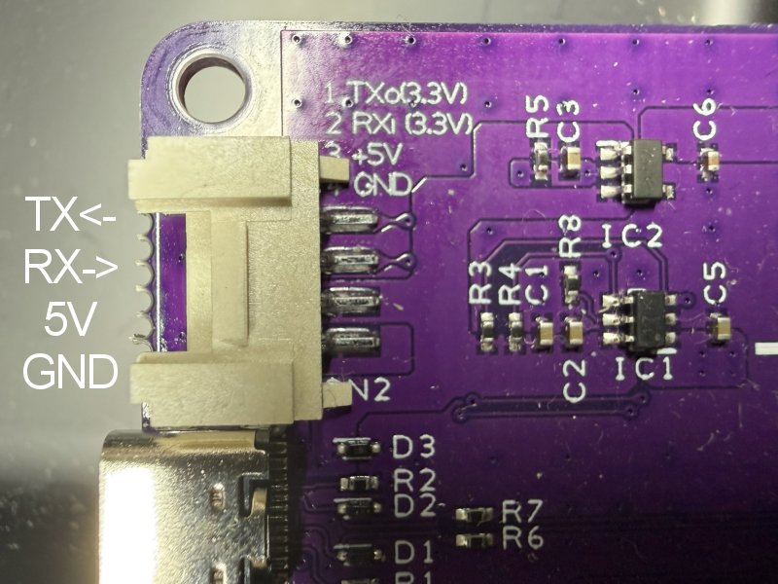
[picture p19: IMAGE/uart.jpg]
UART


### 出力例

```CMD_DEBUGOUT
BRCV_OK20
SKIP : 0a
BIN End
BSCR,0
0: Write Memory 5555:aa
4: Write Memory 2aaa:55
8: Write Memory 5555:a0
12: Write Memory 4000:41
16: Read Memory 4000:ff
20: Compare ff=41
24: JMP
16: Read Memory 4000:ff
20: Compare ff=41
24: JMP
16: Read Memory 4000:ff
20: Compare ff=41
24: JMP
16: Read Memory 4000:ff
20: Compare ff=41
24: JMP
16: Read Memory 4000:41
20: Compare 41=41
28: End Script(PASS)
```CMD_BRCV

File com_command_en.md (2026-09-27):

# MSXPLAYer Game Cassette Adapter Command Specifications

## General Specifications

- 1 line = 1 command (comma-separated)
- Format (maximum 4 arguments):

  ```CMD
  CMD[,ARG1[,ARG2[,ARG3[,ARG4]]]]<CR|LF|CRLF|LFCR>
  ```

- Command names are case-insensitive (converted to uppercase internally)
- Arguments are basically **hexadecimal** (`0x` prefix is allowed)
- If an argument is omitted, the default behavior is used.
- Return values:
  - Normally, `OK` / `FAIL` is returned as the final processing result.
  - During `ERROFF`, OK/FAIL display is suppressed, and only the success/failure counters are updated.

## Command List (Specification Format / Implementation Compliant)

### 1) HSET - Hardware Setting

- **Function**: Configures wait times and compatibility modes for hardware access.
- **Format**: `HSET,[Address],[Data]`
- **Arguments**:
  - `Address` : Setting item number (hexadecimal)
  - `Data` : Setting value (hexadecimal; if omitted, the setting returns to its default value)
- **Response**: `OK` / `FAIL`
- **Notes**:
  - The current firmware supports the following settings.

| Address | Setting Item | Description | Default |
|---|---|---|---|
| `0` | `MEMWAIT` | Wait time after Memory Read/Write (`n x 10ns`) | `0` |
| `1` | `RDWAIT` | `/RD` signal width during Memory Read (`n x 10ns`) | `100` |
| `2` | `WRWAIT` | `/WR` signal width during Memory Write (`n x 10ns`) | `18` |
| `3` | `P6MODE` | PC-6001 16KB mode setting (`0`: OFF / `1` or higher: ON) | `0` |

- **Examples**:
  - `HSET,1,64` : Sets `RDWAIT` to `1000ns = 1us`
  - `HSET,1` : Restores `RDWAIT` to its default value

- **Supplement**:
  - The current setting values can be checked with the `HINF` command.
  - The output of `HINF` includes `MEMWAIT` / `RDWAIT` / `WRWAIT` / `P6MODE`.
  - Specifying an unsupported `Address` results in `FAIL`.

---

### 2) ERROFF - Result Display OFF

- **Function**: Suppresses sequential display of command execution results (OK/FAIL display).
- **Format**: `ERROFF`
- **Arguments**: None
- **Response**: `OK`
- **Notes**:
  - When enabled, statistics are accumulated in `passCount/errCount`.
  - Used to suppress logs during bulk processing (transfers, scripts).

---

### 3) ERRON - Result Display ON + Summary

- **Function**: Cancels `ERROFF` and displays the statistics accumulated during the suppression period.
- **Format**: `ERRON`
- **Arguments**: None
- **Response**:
  - `PASS : <passCount>`
  - `FAIL : <errCount>`
  - Then returns `FAIL` if there were any failures; otherwise returns `OK`
- **Notes**:
  - If there were any failures, `ERRON` itself returns `FAIL`.

---

### 4) BCLR - Buffer Clear (slotMem Initialization)

- **Function**: Fills the internal buffer (64KB) with the specified value.
- **Format**: `BCLR(,[BufferAddress],[Length],[Data])`
- **Arguments**:
  - `BufferAddress` : Start position (defaults to 0 if omitted)
  - `Length` : Length (defaults to the full 64KB range if omitted)
  - `Data` : Fill value (defaults to `0xFF` if omitted)
- **Response**: `OK` / `FAIL`
- **Notes**:
  - Out-of-range values result in `FAIL`.
  - The length may be adjusted to fit the buffer boundaries.

---

### 5) BSND - Buffer Send Host (Device → Host Binary Send)

- **Function**: Sends data from the internal buffer to the PC in binary format.
- **Format**: `BSND,[BufferAddress],[Length]`
- **Arguments**:
  - `BufferAddress` : Start position for transmission
  - `Length` : Number of bytes to send
- **Response**:
  - Binary data is sent to the PC.
  - Then `OK/FAIL` is sent if `displayFlag=true`.
- **Notes**:

---

### 6) BRCV - Buffer Receive Host (Host → Device Binary Receive)

- **Function**: Receives binary data of the specified length from the PC and stores it in `slotMem[]`.
- **Format**: `BRCV,[BufferAddress],[Length]` + (followed by Length bytes of binary data)
- **Arguments**:
  - `BufferAddress` : Storage start position
  - `Length` : Number of bytes to receive
- **Response**:
  - `OK/FAIL` after reception is complete
- **Notes**:
  - Immediately after `BRCV` is executed, the device enters binary receive mode.
  - Out-of-range conditions such as `BufferAddress + Length` exceeding 64KB result in `FAIL`.
  - `CR`, `LF`, `CRLF`, and `LFCR` can be used as command terminators.

---

### 7) HVER - Hardware Version

- **Function**: Displays the hardware name, PCB revision, and firmware version.
- **Format**: `HVER`
- **Arguments**: None
- **Response**:
  - `HARDWARE NAME : <Hardware Name>`
  - `HARDWARE VER : <REV_B2|REV_F|UNKNOWN>`
  - `FIRMWARE VER : <Firmware Version>`
  - `OK`
- **Notes**:
  - PCB REV_B2/REV_F is detected automatically at startup.
  - `UNKNOWN` is displayed if the PCB revision cannot be detected.
  - The output format was changed in 260531 (V1.40).

---

### 8) HINF - Hardware Information

- **Function**: Displays hardware configuration information.
- **Format**: `HINF`
- **Arguments**: None
- **Response**: Each `KEY,VALUE` line + `OK`
- **Notes**:
  - `SLOTNUM`: Number of slots on the reader  
    Indicates the number of physical slots installed on the reader (1 to 4).
  - `SLOTPHY`: Physical slot arrangement information of the reader  
    Indicates the arrangement of physical slots on the reader (`1` = active).

    |bit7-4|bit3|bit2|bit1|bit0|
    |---|---|---|---|---|
    |0000|SLOT3|SLOT2|SLOT1|SLOT0|

    Example: `SLOTNUM:1 / SLOTPHY:2` = one physical slot installed, treated as `SLOT1`

  - `POWERCTRL`: Power control availability  
    Indicates whether power control for the cartridge is available (`1` = yes).
  - `CURRENTSENSOR`: Overcurrent detection availability  
    Indicates whether an overcurrent detection circuit for the cartridge is available (`1` = yes).
  - `PWR12V`: +12V/-12V power availability  
    Indicates whether +12V/-12V power for the cartridge is available (`1` = yes).
  - `SLOTCLOCK`: External slot clock availability  
    Indicates whether a precise 3.58MHz clock supply circuit for the cartridge is available (`1` = yes).
  - `LINEOUT`: Audio line-out availability  
    Indicates whether an output circuit for the cartridge SOUND terminal is available (`1` = yes).
  - `PSGUNIT`: PSG unit availability  
    Indicates whether the reader has PSG sound-source-equivalent functionality (`1` = yes).
  - `LFCR`: Line ending setting value  
    Displays the line ending type of the input command string (`1` means `"\n"` is treated as `0x0d,0x0a`).
  - `COMDBG`: Debug output setting via UART  
    When set to `1`, debug output is enabled on UART.
  - `SCRLOOP`: Maximum LOOP count setting for Script mode  
    Displays the maximum LOOP count for Script mode. The default value is 1000.
  - `MEMWAIT`: Wait value after Read/Write  
    Wait time after Memory Read/Write. Default value is 0.
  - `RDWAIT`: `/RD` width during Memory Read  
    Setting value for how long `/RD` remains LOW during Memory Read. Default value is 10 (180ns).
  - `WRWAIT`: `/WR` width during Memory Write  
    Setting value for how long `/WR` remains LOW during Memory Write. Default value is 10 (180ns).
  - `P6MODE`: PC-6001 cassette mode setting value  
    Displays the PC-6001 16K Read Mode setting value.

---

### 9) HSTS - Hardware Internal Status

- **Function**: Displays internal status (mainly queue remaining count and error status).
- **Format**: `HSTS`
- **Arguments**: None
- **Response**:
  - Displays the queue remaining count equivalent (`count-1`) on one line
  - `OK/FAIL`
- **Notes**:
  - Returns `FAIL` if an error occurred in the executed queue.

---

### 10) SCHK - Slot Cassette Check

- **Function**: Displays slot connection status (power ON not required).
- **Format**: `SCHK`
- **Arguments**: None
- **Response**: One of `0000/0010/0100/0110` + `OK`
- **Notes**: The response is a string in `SLOT3210` order. A slot with an inserted cartridge is shown as `1`.

---

### 11) SPON - Slot Power ON

- **Function**: Powers on the slot, enables the clock, and initializes RESET control, etc.
- **Format**: `SPON`
- **Arguments**: None
- **Response**: `OK/FAIL`
- **Notes**:
  - Returns `FAIL` if overcurrent occurs.

---

### 12) SPOFF - Slot Power OFF

- **Function**: Powers off the slot and returns signals to a safe state.
- **Format**: `SPOFF`
- **Arguments**: None
- **Response**: `OK/FAIL`
- **Notes**:

---

### 13) SRST - Slot Reset

- **Function**: Toggles the slot RESET signal to reset the slot.
- **Format**: `SRST`
- **Arguments**: None
- **Response**: `OK`

---

### 14) SSEL - Slot Select

- **Function**: Sets the default slot number.
- **Format**: `SSEL,[Slot]`
- **Arguments**:
  - `Slot` : `1` or `2`
- **Response**: `OK/FAIL`
- **Notes**:
  - Omitting `Slot` results in `FAIL`.
  - After that, this value is used whenever the slot argument is omitted.

---

### 15) SMRD - Slot Memory Read (1 byte)

- **Function**: Reads 1 byte from slot memory.
- **Format**: `SMRD,[Address](,[Slot])`
- **Arguments**:
  - `Address` : 0000〜FFFF Slot memory address
  - `Slot` : 1 or 2 (uses `defaultSlot` if omitted)
- **Response**:
  - `<addr> : <data>` (example: `1000 : 3F`) + `OK/FAIL`

---

### 16) SMWR - Slot Memory Write (1 byte)

- **Function**: Writes 1 byte to slot memory.
- **Format**: `SMWR,[Address],[Data](,[Slot])`
- **Arguments**:
  - `Address` : 0000〜FFFF Slot memory address
  - `Data` : 00〜FF Write data
  - `Slot` : 1 or 2 (uses `defaultSlot` if omitted)
- **Response**: `OK/FAIL`

---

### 17) SMTR - Slot → Buffer Transfer Read (Bulk Read)

- **Function**: Continuously reads data from the slot into the buffer.
- **Format**: `SMTR,[Address](,[Length],[BufferAddress],[Slot])`
- **Arguments**:
  - `Address` : 0000〜FFFF Slot-side start address
  - `Length` : 0000〜FFFF Read length (maximum if omitted)
  - `BufferAddress` : 0000〜FFFF Buffer storage start position (0 if omitted)
  - `Slot` : 1 or 2 (uses `defaultSlot` if omitted)
- **Response**: Data + `OK/FAIL`

---

### 18) SMTW - Buffer → Slot Transfer Write (Bulk Write)

- **Function**: Continuously writes data from the buffer to the slot.
- **Format**: `SMTW,[Address],[Length],[BufferAddress](,[Slot])`
- **Arguments**:
  - `Address` : 0000〜FFFF Slot-side start address
  - `Length` : 0000〜FFFF Write length
  - `BufferAddress` : Buffer read start position
  - `Slot` : 1 or 2 (uses `defaultSlot` if omitted)
- **Response**: `OK/FAIL`

---

### 19) IORD - IO Read (1 byte)

- **Function**: Reads 1 byte from an IO port.
- **Format**: `IORD,[IO]`
- **Arguments**:
  - `IO` : 0000〜FFFF IO address (treated as 16-bit)
- **Response**:
  - `<io> : <data>` + `OK/FAIL`

---

### 20) IOWR - IO Write (1 byte)

- **Function**: Writes 1 byte to an IO port.
- **Format**: `IOWR,[IO],[Data]`
- **Arguments**:
  - `IO` : 0000〜FFFF IO address
  - `Data` : 00〜FF Write data
- **Response**: `OK/FAIL`

---

### 21) IOTR - IO → Buffer Transfer Read (Implementation Compliant)

- **Function**: Continuously reads from IO and stores the data into the buffer.
- **Format**: `IOTR,[IO],[Length],[BufferAddress](,[Mode])`
- **Arguments (Implementation Compliant)**:
  - `IO` : 0000〜FFFF Start IO address
  - `Length` : 0000〜FFFF Number of reads (bytes)
  - `BufferAddress` : Buffer storage start position
  - `Mode` : If set to `1`, the IO address is incremented on each access; if omitted, the same address is accessed repeatedly (feature added in V1.41 or later)
- **Response**: `OK/FAIL`

---

### 22) IOTW - Buffer → IO Transfer Write (Implementation Compliant)

- **Function**: Continuously writes data from the buffer to IO.
- **Format**: `IOTW,[IO],[Length],[BufferAddress](,[Mode])`
- **Arguments (Implementation Compliant)**:
  - `IO` : 0000〜FFFF Start IO address
  - `Length` : 0000〜FFFF Number of writes (bytes)
  - `BufferAddress` : 0000〜FFFF Buffer read start position
  - `Mode` : If set to `1`, the IO address is incremented on each access; if omitted, the same address is accessed repeatedly (feature added in V1.41 or later)
- **Response**: `OK/FAIL`

---

### 23) BDMP - Buffer Dump (Debug Use)

- **Function**: Displays buffer contents in HEX + ASCII.
- **Format**: `BDMP,[BufferAddress](,[Length])`
- **Arguments**:
  - `BufferAddress` : 0000〜FFFF Start position (0 if omitted)
  - `Length` : 0000〜FFFF Display length (128 if omitted)
- **Response**: Dump lines + `OK`

---

### 24) SDMP - Slot Dump (Slot Memory Dump)

- **Function**: Reads directly from the slot while displaying a dump.
- **Format**: `SDMP,[Address](,[Length],[Slot])`
- **Arguments**:
  - `Address` : 0000〜FFFF Start address (0 if omitted)
  - `Length` : 0000〜FFFF Display length (128 if omitted)
  - `Slot` : 1 or 2 (uses `defaultSlot` if omitted)
- **Response**: Dump lines + `OK/FAIL`

---

### 25) BSCR - Buffer Script Execute (Script Execution)

- **Function**: Executes a script stored in the buffer.
- **Format**: `BSCR,[BufferAddress](,[Slot])`
- **Arguments**:
  - `BufferAddress` : 0000〜FFFF Script start position (0 if omitted)
  - `Slot` : 1 or 2 (uses `defaultSlot` if omitted)
- **Response**: `OK/FAIL`
- **Notes**:
  - Instruction format is 4 bytes per instruction: `[cmd][addr_hi][addr_lo][data]`
  - See the separate section for script details.

---

### 26) FTEST - Factory Test

- **Function**: Executes comprehensive factory tests.
- **Format**: `FTEST`
- **Arguments**: None
- **Response**: Test logs + `OK/FAIL`

---

### 27) LEDRDY / LEDPON / LEDACC - LED Color Setting

- **Function**: Sets LED colors (READY / POWER ON / SLOT ACCESS) in RGB.
- **Format**:
  - `LEDRDY(,[R],[G],[B])`
  - `LEDPON(,[R],[G],[B])`
  - `LEDACC(,[R],[G],[B])`
- **Arguments**:
  - `R` `G` `B` : 0x00〜0xFF (optional; default values are used if omitted)
- **Response**: `OK`

---

### 28) SDBGON - Serial Debug Log ON

- **Function**: Enables debug log output from the serial port.
- **Format**: `SDBGON`
- **Arguments**: None
- **Response**: `OK`
- **Notes**:
  - Execution speed decreases because serial output increases.
  - Be careful of buffer overflows.
  - Serial output is provided through the Grove connector.

---

### 29) _FFU - Bootloader Launch

- **Function**: Switches to FFU mode and enters USB boot mode.
- **Format**: `_FFU`
- **Arguments**: None
- **Response**: Outputs a message and then reboots (no subsequent `OK/FAIL` is returned)

---

### 30) LSCR - Set Maximum LOOP Count for Script Mode

- **Function**: Sets the maximum number of loops used while waiting for a condition in Script mode.
- **Format**: `LSCR(,Maximum LOOP Count)`
- **Arguments**: 0-0xFFFF (default is 1000 if omitted)
- **Response**: `OK`

---

[Added in 260520_VER]

### 31) SMTH - Slot → Buffer Transfer Read (Bulk Read) + HASH

- **Function**: Continuously reads from the slot into the buffer and calculates a 32-bit hash code.
- **Format**: `SMTH,[Address](,[Length],[BufferAddress],[Slot])`
- **Arguments**:
  - `Address` : 0000〜FFFF Slot-side start address
  - `Length` : 0000〜FFFF Read length (maximum if omitted)
  - `BufferAddress` : 0000〜FFFF Buffer storage start position (0 if omitted)
  - `Slot` : 1 or 2 (uses `defaultSlot` if omitted)
- **Response**: `<Length> : <HASH 32bit>` + `OK/FAIL`

---

[Added in 260531_VER]

### 32) RMSET - ROM Mapper Setting

- **Function**: Sets the parameters used by the `RMRD` command.
- **Format**: `RMSET,[Mapper Selector Address],[Bank Read Address],[Bank size]`
- **Arguments**:
  - `Mapper Selector Address` : 0000〜FFFF ROM Mapper bank-switch address. If `FFFF` is specified, bank switching is not performed.
  - `Bank Read Address` : 0000〜FFFF Start address of the bank to read
  - `Bank size` : 0000〜FFFF Capacity of one bank
- **Response**: `OK/FAIL`

---

### 33) RMRD - ROM Mapper Read

- **Function**: Reads a MegaROM inserted in the slot in bulk while switching banks. (The buffer is not used.)
- **Format**: `RMRD,[Start Bank],[Bank Capacity](,[Slot])`
- **Arguments**:
  - `Start Bank` : 00〜FF Starting bank on the slot side
  - `Bank Capacity` : 00〜FF Number of banks to read
  - `Slot` : 1 or 2 (uses `defaultSlot` if omitted)
- **Response**: Read Data + `OK/FAIL`

---

### 34) SMMR - Slot M1 Read

- **Function**: Reads one byte from slot memory using an M1 cycle.
- **Format**: `SMMR,[Address](,[Slot])`
- **Arguments**:
  - `Address`: 0000 to FFFF read address
  - `Slot`: 1 or 2 (uses `defaultSlot` if omitted)
- **Response**: `<Address> : <Data>` + `OK/FAIL`

---

### 35) MDMP - Slot M1 Dump

- **Function**: Reads slot memory using M1 cycles and displays it in hexadecimal and ASCII format.
- **Format**: `MDMP,[Address](,[Length],[Slot])`
- **Arguments**:
  - `Address`: 0000 to FFFF start address (0000 if omitted)
  - `Length`: Number of bytes to display (0080 if omitted)
  - `Slot`: 1 or 2 (uses `defaultSlot` if omitted)
- **Response**: 16-byte hexadecimal/ASCII dump + `OK/FAIL`

---

## Serial Command Examples

### Example 1: Read 0x0000-0x3FFF from the slot and send it to the PC

```CMD_EX1
SPON
SMTR,0000,4000,0000,01
BSND,0000,4000
SPOFF
```

### Example 2: Receive binary data from the PC and write it to 0x8000

```CMD_EX2
SPON
BRCV,0000,2000
(Send 0x2000 bytes of binary data here)
SMTW,8000,2000,0000,01
SPOFF
```

[Added in 260531_VER]

### Example 3: Bulk-read a 1 Mbit MegaROM cassette of ASCII8K type

```CMD_EX3
SPON
RMSET,7000,8000,2000
RMRD,0,10
(Receive 0x20000 bytes of binary data here)
SPOFF
```

## Script Mode

By using a script placed in the buffer, this mode allows data read/write and comparisons
to be executed without communicating with the PC.

## Script Format

- Script format: [Command],[Address(2Byte)],[DATA]...
- Each script is fixed-length at 4 bytes.

### Script Data Format

|Address|+0 Byte|+1 Byte|+2 Byte|+3 Byte|
|---|---|---|---|---|
|**DATA**|Instruction Code|Upper Address|Lower Address|Data|

### Instruction List

|Command|Instruction Name|Description|
|---|---|---|
|0x00|NOP|Does nothing|
|0x01|Read Memory|Executes a Read access to the slot|
|0x02|Write Memory|Writes DATA to the slot (`LastData` is overwritten with DATA)|
|0x03|Read IO|Executes an IO-based Read access to the slot (`LastData` becomes the read DATA)|
|0x04|Write IO|Executes an IO-based Write access to the slot (`LastData` is overwritten with DATA)|
|0x05|Wait|Waits for the number of milliseconds specified by `address`|
|0x06|Compare|Compares `LastData` with `data`; if they match, the next instruction is skipped|
|0x07|AND|Calculates `LastData [AND] DATA`; if the result is `0x00`, the next instruction is skipped|
|0x08|OR|Calculates `LastData [OR] DATA`; if the result is `0x00`, the next instruction is skipped|
|0x09|XOR|Calculates `LastData [XOR] DATA`; if the result is `0x00`, the next instruction is skipped|
|0x0A|JMP|Skips instructions by the amount in DATA (`0x00-7F` = forward / `0x80-FF` = backward)|
|0x0B|PUSH|Writes `LastData` to the buffer memory location specified by `address`|
|0xFE|Abort|Ends script execution with failure|
|0xFF|End|Ends script execution with success|

*The JMP instruction causes script failure if it is executed at the same location a certain number of times (default: 1000).*  
*This value can be changed with the `LSCR` command.*

### Script Example

This can be executed with the following command:

```CMD_BRCV
BRCV,0,20
(Send the following binary)
BSCR,0
```

|Binary Value|Command|Description|
|---|---|---|
|0x02,0x55,0x55,0xaa|[Write Memory] Address:0x5555 Data:0xaa|Write 0xAA to 0x5555|
|0x02,0xaa,0xaa,0x55|[Write Memory] Address:0xaaaa Data:0x55|Write 0x55 to 0xAAAA|
|0x02,0x55,0x55,0xa0|[Write Memory] Address:0x5555 Data:0xa0|Write 0xA0 to 0x5555|
|0x02,0x40,0x00,0x41|[Write Memory] Address:0x4000 Data:0x41|Write 0x41 to 0x4000|
|0x01,0x40,0x00,0x00|[Read Memory] Address:0x4000|Read data from 0x4000|
|0x06,0x00,0x00,0x41|[Compare] Data:0x40|Compare with the previously read data; if it is 0x40, skip the next instruction|
|0x0a,0x00,0x00,0xfe|[JMP] -2|Return to the instruction two steps before (that is, loop until 0x4000 becomes 0x40)|
|0xff,0x00,0x00,0x00|End|End script|

## Debugging

By executing the `SDBGON` command, execution logs can be obtained from the Grove connector (UART).  
However, enabling this feature slows execution, so it should normally remain disabled.

The serial port uses 3.3V levels, and the wiring is as shown below.  
UART

### Output Example

```CMD_DEBUGOUT
BRCV_OK20
SKIP : 0a
BIN End
BSCR,0
0: Write Memory 5555:aa
4: Write Memory 2aaa:55
8: Write Memory 5555:a0
12: Write Memory 4000:41
16: Read Memory 4000:ff
20: Compare ff=41
24: JMP
16: Read Memory 4000:ff
20: Compare ff=41
24: JMP
16: Read Memory 4000:ff
20: Compare ff=41
24: JMP
16: Read Memory 4000:ff
20: Compare ff=41
24: JMP
16: Read Memory 4000:41
20: Compare 41=41
28: End Script(PASS)
```

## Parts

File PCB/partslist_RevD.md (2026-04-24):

|Ref Name|Original Component|Description|Maker|Component|Value|Qty|Package|
|---|---|---|---|---|---|---|---|
|RN1-10|4D03WGJ0103T5E|Resistor Networks & Arrays 10K 5% CONVEX SQUARE 4x0603|UNI-ROYAL|4D03WGJ0103T5E|10K x 4|10|YC164JR07220RL|
|R9, R11|0402WGF1001TCE|Thick Film Resistors - SMD 0402 1/16W 5% 5K T/R-10000|UNI-ROYAL|0402WGF1001TCE|1K|2|RESC1005X40N|
|R3-5, R10|0402WGF1002TCE|Thick Film Resistors - SMD 0402 1/16W 5% 10K T/R-10000|UNI-ROYAL|0402WGF1002TCE|10K|4|RESC1005X40N|
|R1-2|0402WGF5101TCE|Chip Resistor - Surface Mount 5.1KOhms +/-1% 1/16W 0402 RoHS|UNI-ROYAL|0402WGF5101TCE|5.1K|2|RESC1005X40N|
|R6-7|0402WGJ0270TCE|Resistor: thick film; SMD; 0402; 27; 62.5mW; +/-1%; 50V; -55155C|UNI-ROYAL|0402WGJ0270TCE|27|2|RESC1005X40N|
|R8|0402WGJ0134TCE|Thick Film Resistors - SMD 0402 1/16W 5% 130K T/R-10000|UNI-ROYAL|0402WGJ0134TCE|130K|1|RESC1005X40N|
|CN1|5077CR-16-SMC2-BK-TR|USB-C connector USB2.0|G-Switch|GT-USB-7010ASV||1|USER|
|C24-25|04025A150CAT2A|Multilayer Ceramic Capacitors MLCC - SMD/SMT 50V 15pF C0G 0402 .25pF Tol|Samsung|CL05C150JB5NNNC|15pF|2|CAPC1005X56N|
|CN2|114020164|Grove Female Header - SMD-4P-2.0mm HY2.0-4P|Megastar|ZX-HY2.0-4PWT||1|114020164|
|Y1|ABM8-272-T3|Crystal, 12 MHz, SMD, 3.2mm x 2.5mm, 30 ppm, 10 pF, 30 ppm, ABM8 Series|ABRACON|ABM8-272-T3|12MHz 30ppm|1|ABM8272T3|
|L1|AOTA-B201610S3R3-101-T|Power Inductors - SMD IND 3.3uH|ABRACON|AOTA-B201610S3R3-101-T|3.3uH|1|AOTAB201610S3R3101T|
|IC1|CH217K|USB Current Limiting Power Distribution Switch|WCH|CH217K||1|SOT95P280X140-6N|
|C1-3, C5, C8-9|CL05A106MP5NUNC|0402 CAP CER 10UF 10V X5R|Samsung|CL05A106MP5NUNC|10uF|6|CAPC1005X55N|
|C6, C12, C18|CL05A225MQ5NNNC|CAP CER 2.2UF 6.3V X5R 0402|Samsung|CL05A225MQ5NNNC|2.2uF|3|CAPC1005X55N|
|C4, C7, C10-11, C13-17, C19-23|CL05B104KO5NNWC|Cap Ceramic 0.1uF 16V X7R 10% SMD 0402 125C Cardboard T/R|Samsung|CL05B104KO5NNWC|0.1uF|14|CAPC1005X55N|
|CN3|CR22B-50D-2.54DS_70_|Standard Card Edge Connectors 2.54mm 25pinx2|HIROSE|ED50BGFBK||1|CR22B50D254DS70|
|IC4|RP2350B|Dual Arm Cortex-M33 or dual Hazard3 RISC-V processors @ 150MHz|Raspberry Pi|RP2350B ||1|QFN40P1000X1000X90-81N-D|
|LED1|SK6812SMINI-ER|3.5x2.8x1.8 mm, 0.2 W intelligent externally controlled surface-mount device (SMD) type LED|OPSCO Optoelectronics|SK6812SMINI-ER||1|QBLP677RGBHIGHBRIGHT|
|SW1|SKRPACE010|Tactile Switch SPST 2.5mm 4.2mm x 3.2mm Surface Mount|ALPSALPINE|SKRPACE010||1|SW_SKRPACE010|
|SW2|||Not implemented|Not implemented||0||
|CN4|||Not implemented|Not implemented||0||
|D1-3|STS521050B750|ESD Suppressors / TVS Diodes TVS ESD SOD-523  5 V|HXY MOSFET |HSTS521050B750||3|SODFL1608X70N|
|IC3|W25Q16JVUXSM|16Mbit USON-8-EP(2x3) Memory (ICs) RoHS|Winbond|W25Q16JVUXIQ||1|SON50P300X200X60-9N|
|IC2|XC6222D331MR-G|LDO Voltage Regulators|TOREX|XC6222D331MR-G||1|SOT95P280X130-5N|

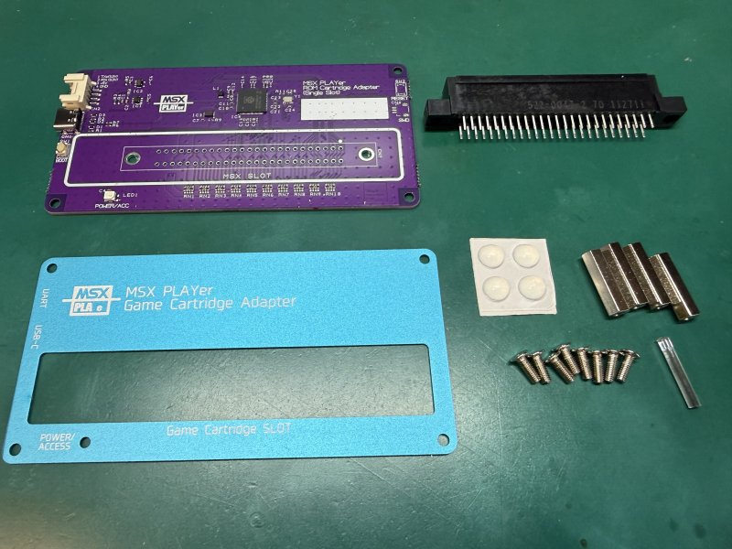
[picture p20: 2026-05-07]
IMAGE/parts_image001.jpg

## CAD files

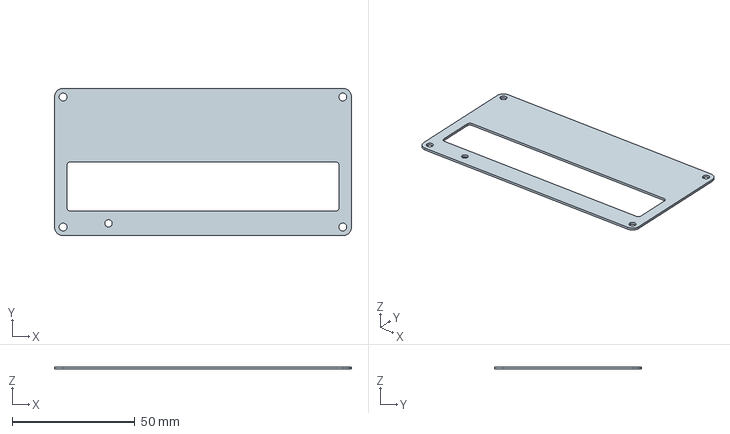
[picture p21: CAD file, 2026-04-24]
PCB/PANEL_DATA/REVE_PANEL_T10.stp
121.0 x 60.0 x 1.00 mm

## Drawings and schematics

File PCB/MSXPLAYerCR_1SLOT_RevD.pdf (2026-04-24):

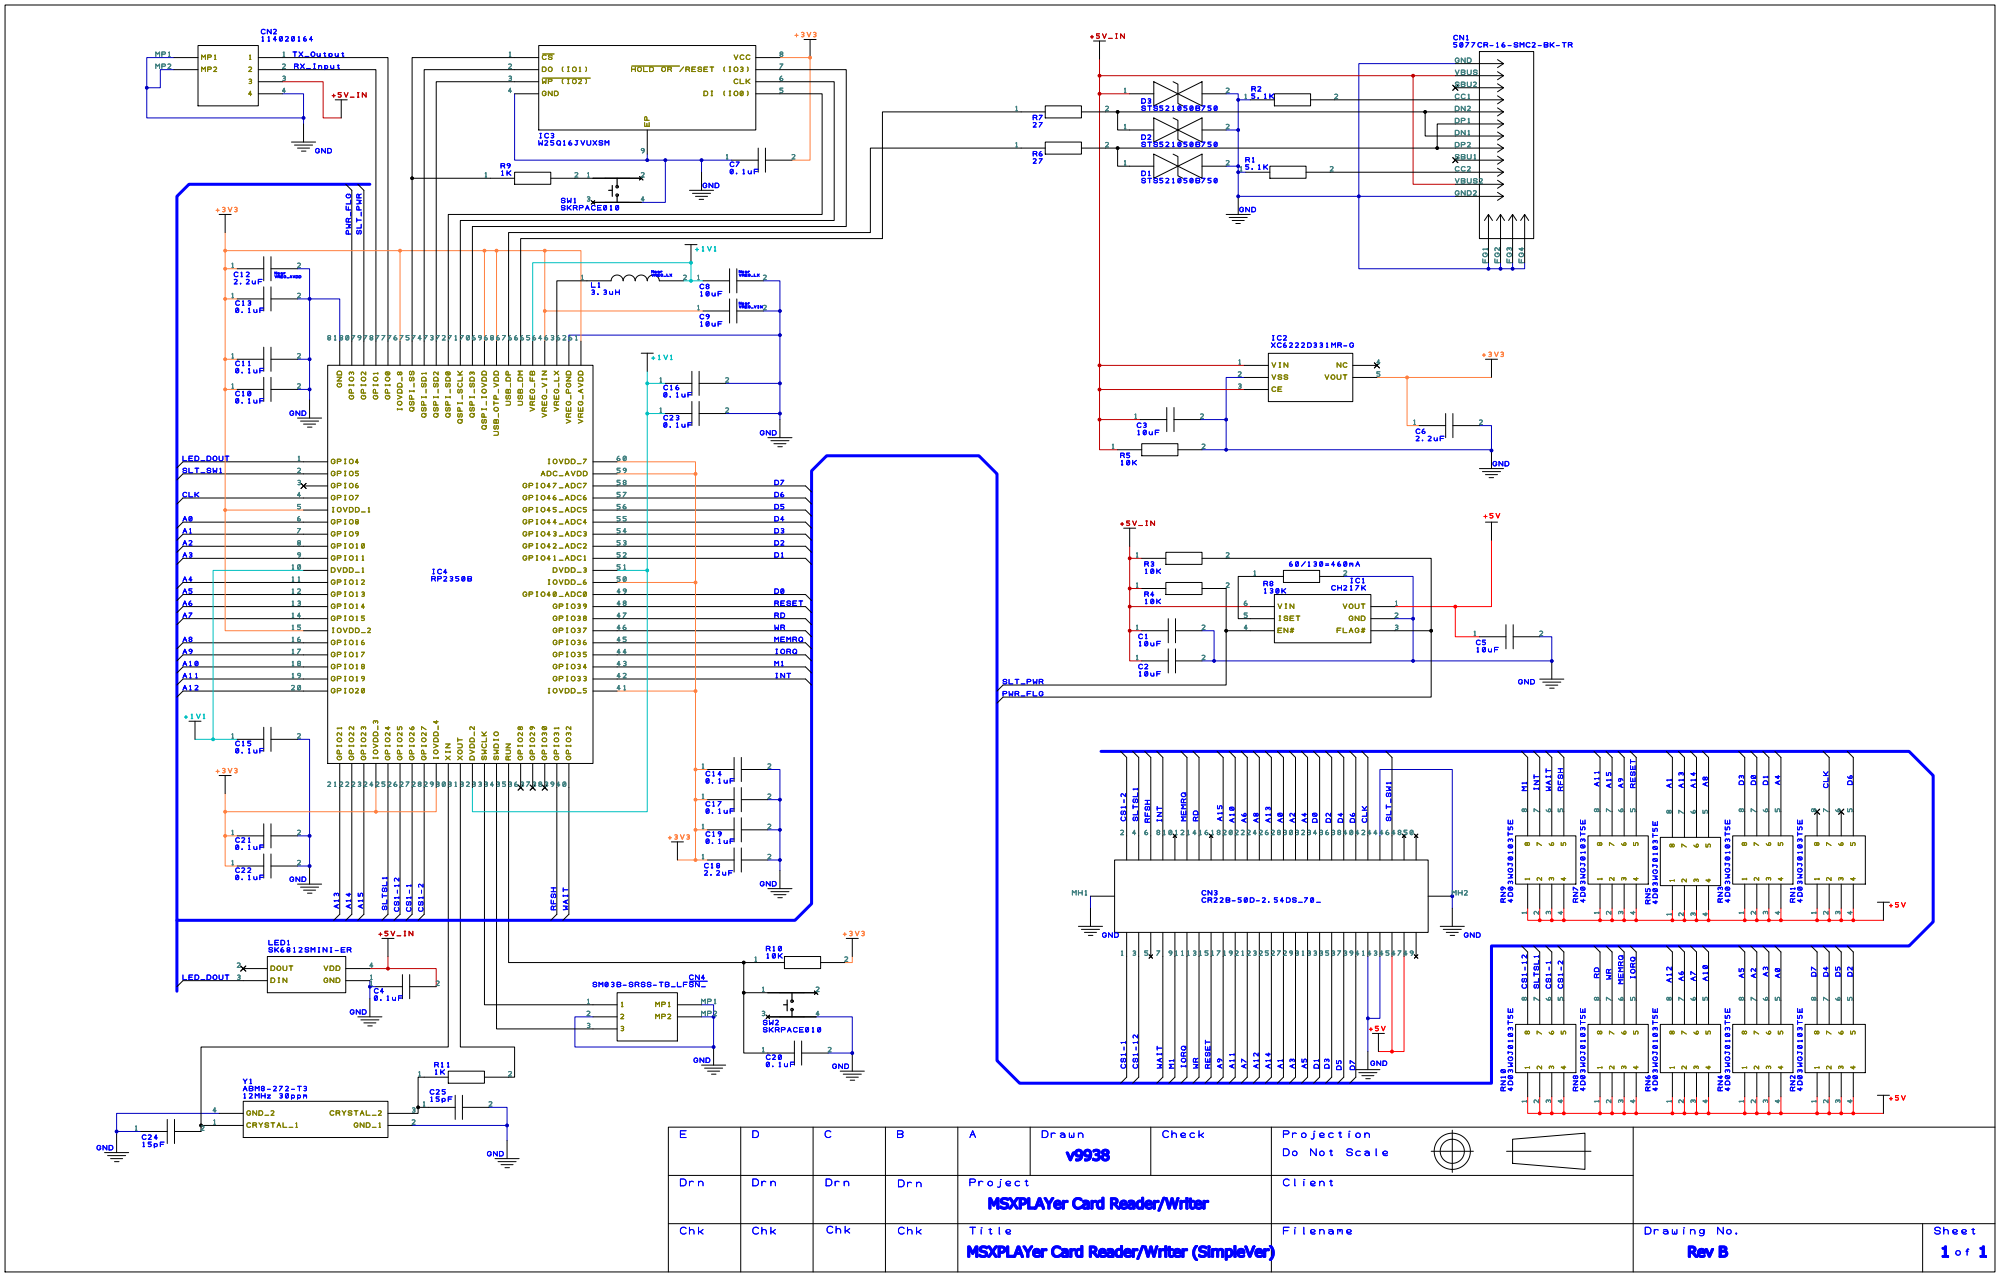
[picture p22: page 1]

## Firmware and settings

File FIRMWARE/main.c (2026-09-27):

////////////////////////////////////////////////////////////////////////
//
// MSXPLAYer Gaming Cartridge Reader/Writer
// Copyright 2025 @V9938
//	
//	25/10/20 V0.5		1st version (for Test)
//	25/11/05 V0.6		暫定Release版
//                      PCB Version B対応 (1Slot,2Slot版)
//                      コマンドリストを commands.c/h に分割
//                      ポートリストを ports.c/h に分割
//                      stdarg.h を追加 (cdc_printf の可変引数対応)
//                      z80AddressVaild / bufAddressVaild の不適切な戻り値を修正
//                      tud_cdc_rx_cb 内の skipByte の扱い修正
// (以降公開版)
//  26/04/06 V1.0       正式Release版(1SLOT版) 
//                      Single Slot版 PCB Rev C/D対応
//                      SLOT IFの電圧を3.3V>5Vに変更
//                      CLOCK端子の対応
//                      量産テスト向け機能の追加
//                      Scriptモードの追加など
//  26/04/13 V1.1       DTR信号監視の修正 
//                      受信キャラクタLFCR判定を接続毎にリセットするように変更
//                      CDCのENDPOINTのバッファーサイズを1024>64に変更
//  26/04/14 V1.11      POWER OFF時の電源安定待ち時間を1ms>100msに変更
//  26/04/18 V1.12      LSCRを追加、スクリプトのLoop回数を外部から設定可能にした。（出荷FW)
//  26/05/20 V1.20      SMTHコマンドの追加、スクリプトのPUSH命令を追加
//  26/05/20 V1.21      MSX初期のROMカセットではアクセス速度が<180ns以上ものが散見されたので
//                      読み込みタイミングを調整した
//  26/05/28 v1.30      BS6101を採用したASCII3 ROMの動作不良対策で書き込み時のRD信号をPushPullに変更
//  26/05/31 v1.40      HVERの表示変更、Megarom Read支援コマンドRMSET/RMRDを追加
//  26/06/01 v1.41      IOTRのIOアドレス加算の仕様を変更
//  26/06/01 v1.42      RMRDのBANK指定のバグを修正
//  26/06/01 v1.43      CDC OUTPUT BUFFERのmutex制御を追加
//  26/09/07 v2.00      PCB REV_B2/REV_F判別、REV_Fデータバスバッファ制御を追加
//                      REV_F用Factory GPIO Testを追加
//                      Pico SDK 2.3.0、TinyUSB 0.21.0、RP2354B独自ボード定義へ更新
//                      PCB REV_F判定をGPIO6出力とGPIO5入力の比較方式へ変更
//  26/09/27 v2.10      USB CDC大量転送時の送受信安定性を改善
//                      CDC送信キューと送信中状態を一元管理し、Core間排他制御を修正
//                      ホスト受信遅延時のTX FIFO上書きを禁止し、バックプレッシャー制御を追加
//                      USB切断時の送信キュー破棄とDTR/RTS変更時のキュー維持に対応
//                      TinyUSB 0.21.0へUSBDイベントキュー飽和時の復旧パッチを追加
//                      BRCVのLF、CR、CRLF、LFCR終端処理を修正
//                      時間依存のメモリ・IOアクセス関数をRAM実行へ変更
//
////////////////////////////////////////////////////////////////////////

/*
 * Copyright (c) 2024 Raspberry Pi (Trading) Ltd.
 * SPDX-License-Identifier: BSD-3-Clause
 *
 * 修正点:
 *  - コマンドリストを commands.c/h に分割
 *  - ポートリストを ports.c/h に分割
 *  - parse_hex_string 等の挙動は保持
 *  - stdarg.h を追加 (cdc_printf の可変引数対応)
 *  - z80AddressVaild / bufAddressVaild の不適切な戻り値を修正 (bool を返す)
 *  - tud_cdc_rx_cb 内の skipByte の扱い修正（スキップ時に書き込みを行わない）
 *
 */

#include <stdio.h>                              // printf 用 // 標準入出力
#include <stdlib.h>                             // 標準ライブラリ
#include <bsp/board_api.h>                      // ボード API // TinyUSB/board 初期化
#include <tusb.h>                               // TinyUSB core

#include <string.h>                             // 文字列操作 // strcpy/strtok 等
#include <stdbool.h>                            // bool 型
#include <ctype.h>                              // toupper() 等
#include <stdarg.h>                             // va_list 等 (cdc_printf 用) // 追加

#include "hardware/pwm.h"
#include "hardware/gpio.h"                      // GPIO API // RP2040
#include "hardware/timer.h"                     // タイミング API
#include "hardware/structs/io_bank0.h"
#include "pico/multicore.h"                     // マルチコア API // core1 起動
#include "pico/stdio.h"                         // stdio 初期化
#include "pico/mutex.h"                         // mutex
#include "hardware/clocks.h" // set_sys_clock_khz  // クロック API
#include "ws2812.pio.h"                         // WS2812 PIO プログラム
#include "hardware/structs/systick.h"           // systick 直接操作 (shortpause マクロ)
#include "pico/bootrom.h"                       // reset_usb_boot 等
#include "boot/picoboot.h"
#include "boot/picobin.h"
#include "pwm_low_hiz.pio.h"                    // コンパイル済みPIOプログラムヘッダ
#include "pwm_push_pull.pio.h"                  // REV_F用Push-Pullクロック
#include "pico/version.h"                       // SDKのバージョン情報
#include "build_timestamp.h"                    // TimeStampのヘッダーファイル

#include "commands.h"                           // 別ファイルに分割したコマンドテーブル // commands.c 参照
#include "ports.h"                              // 別ファイルに分割したボードピン定義 // ports.c 参照
#include "slot_bus.h"                           // PCBリビジョン別スロットバス処理
#include "factory_test.h"                        // PCBリビジョン別出荷GPIOテスト

//#define HW_NAME     "ILF ROM Cassette Reader V2" // ハード名
#define HW_NAME     "ILF ROM Cassette Reader V2" // ハード名

// Hardware Infomation
#define HWINFO_SLOTNUM          1           // スロット数
#define HWINFO_POWERCTRL        1           // SLOT Power Control          (0無/1有)
#define HWINFO_SLOTPHY          2           // SLOTの物理配置情報　bit0 Slot0 / bit1 Slot1 / bit2 Slot2 /bit3 Slot3     
//#define HWINFO_CURRENTSENSOR    1           // 電流センサ                   (0無/1有)
#define HWINFO_PWR12V           0           // 12V/-12V DCDC Unit          (0無/1有)
#define HWINFO_SLOTCLOCK        0           // スロットのクロック供給        (0無/1有)
#define HWINFO_LINEOUT          0           // スロットのLineOut            (0無/1有)
#define HWINFO_PSGUNIT          0           // PSGUNIT                     (0無/1有)

//#define PCBVER_B
#define PCBVER_B2_F

#ifdef PCBVER_B2_F
//Rev B2/F
    #define HW_VERSION  (pcbRevValid ? (pcbRevF ? "REV_F" : "REV_B2") : "UNKNOWN") // ハードリビジョン
    #define HWINFO_CURRENTSENSOR    1           // 電流センサ                   (0無/1有)
    #define SlotPowerON()            gpio_put(2, 0)
    #define SlotPowerOFF()           gpio_put(2, 1)
#endif

#ifdef PCBVER_B 
//Rev B
    #define HW_VERSION  "REV_B"                      // ハードリビジョン
    #define HWINFO_CURRENTSENSOR    0           // 電流センサ                   (0無/1有)
    #define SlotPowerON()            gpio_put(2, 1)
    #define SlotPowerOFF()           gpio_put(2, 0)
#endif


#define IS_RGBW true
#define NUM_PIXELS 1
#define CLOCK_PIN 7

#ifdef PICO_DEFAULT_WS2812_PIN
#define WS2812_PIN PICO_DEFAULT_WS2812_PIN      // デフォルトの WS2812 ピン
#else
    #ifdef PCBVER_B 
    //Rev B
        #define WS2812_PIN 6                            // デフォルト GP6 を使用 // 元の定義に合わせる
    #endif
    #ifdef PCBVER_B2_F
    // Rev B2-
        #define WS2812_PIN 4                            // デフォルト GP4 を使用 // 元の定義に合わせる
    #endif
#endif

#define BIN_DEBUG 1
// #define MAX_STRING   32                          // (注) commands.h と整合
#define MAX_ARG      4
#define RX_BUF_SIZE  2048
#define ASCII_LF     0x0A
#define ASCII_CR     0x0D
#define CMD_BUF_NUM  2048
#define DATABUF_SIZE 64*1024                     // 64KB バッファ
#define CMP_LOOP     1000
uint16_t cmpLoopMax = CMP_LOOP;


#define LED_PIN      25
#define shortpause(a){systick_hw->cvr=0;while(systick_hw->cvr>a){};} // systick を使った短待ち

//HSET定義
#define HSET_ADDRESS_MEMWAIT 0
#define HSET_DEFNUM_MEMWAIT 0                     // MEMWAIT初期値(0ns)

#define HSET_ADDRESS_RDWAIT 1                     
#define HSET_DEFNUM_RDWAIT 100                   // MEM Read時のRD信号幅 初期値(1000ns)

#define HSET_ADDRESS_WRWAIT 2
#define HSET_DEFNUM_WRWAIT 18                    // MEM Read時のWr信号幅 初期値(180ns)

#define HSET_ADDRESS_P6MODE 3
#define HSET_DEFNUM_P6MODE false                // PC6001 modeの 初期値(無効)


uint8_t slotMem[DATABUF_SIZE];                    // ワークバッファ (64KB) // スロットデータ保存領域
uint8_t defaultSlot = 1;                          // デフォルトスロット番号 // SSEL 未指定時使用
bool displayFlag = true;                          // 結果出力フラグ // true: OK/FAIL を表示
uint32_t passCount = 0;                           // 表示OFF時の成功カウント(スクリプトモードのモードでも使います)
uint32_t errCount = 0;                            // 表示OFF時の失敗カウント(スクリプトモードのモードでも使います)
int lastError = 0;                                // 最後のエラーコード
bool sltPower = false;                            // スロット電源状態フラグ // true = ON
bool sltAcc = false;                              // スロットアクセス中フラグ // true = アクセス中
bool crlfFlag = false;                            // CR/LF 判定フラグ (BRCV 用)
bool comdbgFlag = false;                          // CMD実行LOGフラグ
int wrWait = HSET_DEFNUM_WRWAIT;                  // Memory Write時のwr信号Low時間(n x 10ns)
int rdWait = HSET_DEFNUM_RDWAIT;                  // Memory Read時のrd信号Low時間(n x 10ns)
int memWait = HSET_DEFNUM_MEMWAIT;                // Memory R/W時のアクセスのWait時間(n x 10ns)
bool p6_16kbMode = false;                         // PC6001 mode
bool pcbRevF = false;                             // PCB REV_F判定フラグ
bool pcbRevValid = true;                          // PCBリビジョン判定結果
static const slot_bus_ops_t *slot_bus_ops = &slot_bus_b2_ops;

void init_all_pins(void);

void slot_bus_select(bool rev_f) {
    slot_bus_ops = rev_f ? &slot_bus_rev_f_ops : &slot_bus_b2_ops;
}

void slot_bus_data_input(void) {
    slot_bus_ops->data_input();
}

void slot_bus_init_pins(uint64_t out_mask) {
    slot_bus_ops->init_pins(out_mask);
}

void slot_bus_control_write(uint64_t mask, uint64_t value) {
    slot_bus_ops->control_write(mask, value);
}

int __not_in_flash_func(slotM1ReadData)(uint8_t slot, uint16_t address, uint8_t *data) {
    return slot_bus_ops->m1_read(slot, address, data);
}

int __not_in_flash_func(slotReadData)(uint8_t slot, uint16_t address, uint8_t *data) {
    return slot_bus_ops->mem_read(slot, address, data);
}

int __not_in_flash_func(slotWriteData)(uint8_t slot, uint16_t address, uint8_t data) {
    return slot_bus_ops->mem_write(slot, address, data);
}

int __not_in_flash_func(slotReadIO)(uint16_t address, uint8_t *data) {
    return slot_bus_ops->io_read(address, data);
}

int __not_in_flash_func(slotWriteIO)(uint16_t address, uint8_t data) {
    return slot_bus_ops->io_write(address, data);
}

uint slice_num;

PIO pio = pio0;                                  // PIO0 を使用
// ===== ステートマシン 0: WS2812 制御 (GPIO4) =====
uint sm_ws2812 = 0;
// ===== ステートマシン 1: CLK3.58MHz (GPIO7) =====
uint sm_slotclk = 1;

#define LED_STATUS_IDLE  0
#define LED_STATUS_READY 1
#define LED_STATUS_PON   2
#define LED_STATUS_ACC   3
bool ledChgReq  = false;
uint8_t ledColorR[4];
uint8_t ledColorG[4];
uint8_t ledColorB[4];

typedef enum {
    FACTORY_LED_NONE,
    FACTORY_LED_PASS,
    FACTORY_LED_FAIL
} factory_led_result_t;

volatile factory_led_result_t factoryLedResult = FACTORY_LED_NONE;

// スクリプトモードのエラーコード定義
typedef enum {
    SUCCESS = 0,
    ERR_INVALID_COMMAND = -1,
    ERR_FUNCTION_FAILED = -2,
    ERR_INVALID_SLOT = -3,
    ERR_OUT_OF_BOUNDS = -4,
    ERR_LOOP_OUT = -5
} ErrorCode;

// スクリプト実行エンジン状態を保存する構造体
typedef struct {
    uint8_t lastData;      // 直近の命令で使用したdata
    uint16_t instructionPC; // 現在の命令ポインタ
    uint32_t waitEndTime;   // Wait終了時刻（マイクロ秒）
    uint8_t isWaiting;      // Wait状態フラグ
} ExecutionState;

ExecutionState execState = {0, 0, 0, 0};

// GPIO組み合わせテーブル（実装はfactory_test_*.cへ分離）
#if 0
typedef struct {
    uint gpio_out;
    uint gpio_check;
} GPIO_PAIR;

const GPIO_PAIR gpio_pairs[] = {
    {7, 9},      // GPIO7-9
    {8, 10},     // GPIO8-10
    {11, 13},    // GPIO11-13
    {12, 14},    // GPIO12-14
    {15, 17},    // GPIO15-17
    {16, 18},    // GPIO16-18
    {19, 21},    // GPIO19-21
    {20, 22},    // GPIO20-22
    {23, 25},    // GPIO23-25
    {24, 26},    // GPIO24-26
    {27, 32},    // GPIO27-32
    {31, 33},    // GPIO31-33
    {34, 36},    // GPIO34-36
    {35, 37},    // GPIO35-37
    {38, 40},    // GPIO38-40
    {39, 41},    // GPIO39-41
    {42, 45},    // GPIO42-45
    {43, 46},    // GPIO43-46
    {44, 47}     // GPIO44-47
};

const int NUM_GPIO_PAIRS = sizeof(gpio_pairs) / sizeof(GPIO_PAIR);

// REV_F GPIO組み合わせテーブル（RP2350B QFN端子で隣接しないGPIOを組み合わせる）
const GPIO_PAIR gpio_pairs_rev_f[] = {
    {7, 31},     // 出力専用GPIO
    {24, 32},
    {25, 33},
    {26, 34},
    {27, 35},
    {37, 8},
    {38, 9},
    {18, 21},    // 通常GPIO
    {19, 22},
    {20, 36},
    {23, 39}
};

// REV_F BUFDIRチェック用テーブル（gpio_outはバッファ側GPIO）
const GPIO_PAIR gpio_pairs_rev_f_buf[] = {
    {40, 10},
    {41, 11},
    {42, 12},
    {43, 13},
    {44, 14},
    {45, 15},
    {46, 16},
    {47, 17}
};

const int NUM_GPIO_PAIRS_REV_F = sizeof(gpio_pairs_rev_f) / sizeof(GPIO_PAIR);
const int NUM_GPIO_PAIRS_REV_F_BUF = sizeof(gpio_pairs_rev_f_buf) / sizeof(GPIO_PAIR);
#endif

// MEGAROM Mapperの設定値
typedef struct {
    bool megarom;            // 非MegaROM or MegaROM 
    uint16_t mapSelAddress;  // MEGAROM Mapperの選択アドレス 
    uint16_t romReadAddress; // Mapper Read Address
    uint16_t romReadSize;    // Mapper Read size
} MegaROM_Mapper;

MegaROM_Mapper romMapper ;



// MUTEX
auto_init_mutex(cmdcount_mutex);
auto_init_mutex(cdc_output_mutex);
auto_init_mutex(cdc_producer_mutex);


// PIO にデータを流すラッパー
static inline void put_pixel(uint32_t pixel_grb) {
    pio_sm_put_blocking(pio0, sm_ws2812, pixel_grb << 8u); // PIO0 SM0 にデータをブロッキングで送信 // WS2812 用データ送信
}

// gpioc_hi のマスク書き換えヘルパ
static inline void gpiohi_put_masked(uint32_t mask, uint32_t value) {
    gpioc_hi_out_xor((gpioc_hi_out_get() ^ value) & mask); // 現在値と XOR → マスク適用で出力変更
    gpioc_hi_oe_xor((gpioc_hi_oe_get() ^ (~value)) & mask); // 現在値と XOR → マスク適用で出力変更
}

static inline void gpiolo_put_masked(uint32_t mask, uint32_t value) {
    gpioc_lo_out_xor((gpioc_lo_out_get() ^ value) & mask); // 現在値と XOR → マスク適用で出力変更
    gpioc_lo_oe_xor((gpioc_lo_oe_get() ^ (~value)) & mask); // 現在値と XOR → マスク適用で出力変更
}

// GRB を 32bit に合成するユーティリティ
static inline uint32_t urgb_u32(uint8_t r, uint8_t g, uint8_t b) {
    return  ((uint32_t) (r) << 16)  | ((uint32_t) (g) << 8) | (uint32_t) (b); // GRB 順にビットシフト
}

//void custom_cdc_task(void);
void cdc_task(void); // 前方宣言
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
int main(void)
{

    // Initialize TinyUSB stack
    board_init();                                   // board 初期化

    // mutex_init(&usb_task_mutex);                 // mutex 初期化
    // gpio_init(LED_PIN); gpio_set_dir(LED_PIN, GPIO_OUT);
    // gpio_init(MOTOR_PIN); gpio_set_dir(MOTOR_PIN, GPIO_OUT);

    // let pico sdk use the first cdc interface for std io
    stdio_init_all();                                // stdio を USB CDC にルーティング (可能なら)

    init_all_pins();                                 // GPIO を全初期化 (ports.c の配列を使用)

    pio_gpio_init(pio, CLOCK_PIN);
    gpio_disable_pulls(CLOCK_PIN);


    // PIOプログラムをロード
    if (pcbRevF) {
        uint clkoffset = pio_add_program(pio, &pwm_push_pull_program);
        pwm_push_pull_program_init(pio, sm_slotclk, clkoffset, CLOCK_PIN);
    } else {
        uint clkoffset = pio_add_program(pio, &pwm_low_hiz_program);
        pwm_low_hiz_program_init(pio, sm_slotclk, clkoffset, CLOCK_PIN);
    }

//    SlotPowerON();

    uint offset = pio_add_program(pio, &ws2812_program); // PIO プログラムを追加
    ws2812_program_init(pio, sm_ws2812, offset, WS2812_PIN, 800000, IS_RGBW); // WS2812 初期化
//   ws2812_program_init(pio0, 0, offset, WS2812_PIN, 800000, IS_RGBW); // WS2812 初期化

    tusb_init();                                     // TinyUSB スタック初期化

    // TinyUSB board init callback after init
    if (board_init_after_tusb) {
        board_init_after_tusb();                     // ボード固有の後処理呼び出し (存在する場合)
    }

    // コマンドバッファ初期化
    for(int i=0;i<CMD_BUF_NUM;i++) commandBufs[i].valid = false; // 全エントリ無効化
    write_idx = 0;                                    // 索引初期化
    read_idx = 0;
    count = 0;
    ledColorInit();                                    //LED Color Table初期化

    multicore_launch_core1(core1_entry);              // Core1 にコマンド処理ループを起動
//    enable_clock();

    printf("\nMSXPlayer Game Card Adapter for RP2350\nCopyright @v9938\n"); // 起動画面
    printf("Release Data: %s\n\n",__DATE__);

    printf("Ready to Command\n");                     // 準備完了表示
    // main run loop
    while (1) {
        // TinyUSB device task | must be called regurlarly
        tud_task();                                   // TinyUSB の定期処理 (USB イベント処理)
       
        // cdc tasks
        cdc_task();                                   // CDC キュー送受信処理
        ledTask(false);                                    // LED 更新
    }

    // indicate no error
    return 0;
}

void cdc_task(void)
{
//  if (tud_cdc_connected()){                         // CDC 接続されているか
  if (tud_ready()){                         // CDC 接続されているか(DTS無し対策)
//        printf("tud_ready\n");
        //受信TASK
        if (tud_cdc_available()) {                    // 受信データがあるか
            tud_cdc_rx_cb(0);                         // 受信コールバック処理 (read とパースを行う)
        }else{
//            sleep_ms(1);                              // 無ければ少し待つ
        }
    }else{
//         printf("Not Ready\n");
    }

    // 送信TASK
    // CDC出力バッファから実際にUSBに出力
    if (tud_ready() && tud_cdc_n_ready(0)) {
        int tx_index = -1;
        size_t tx_offset = 0;
        size_t tx_remain = 0;
        mutex_enter_blocking(&cdc_output_mutex);
        if (!cdc_tx.active && cdc_tx.count > 0 && cdc_tx.queue[cdc_tx.read_index].state == CDC_MSG_READY) {
            cdc_tx.length = (cdc_tx.queue[cdc_tx.read_index].binLength == 0) ?
                            strlen(cdc_tx.queue[cdc_tx.read_index].buf) :
                            cdc_tx.queue[cdc_tx.read_index].binLength;
            cdc_tx.offset = 0;
            cdc_tx.active = true;
            cdc_tx.queue[cdc_tx.read_index].state = CDC_MSG_SENDING;
        }
        if (cdc_tx.active) {
            tx_index = cdc_tx.read_index;
            tx_offset = cdc_tx.offset;
            tx_remain = cdc_tx.length - cdc_tx.offset;
        }
        mutex_exit(&cdc_output_mutex);

        if (tx_index >= 0) {
            uint32_t available = tud_cdc_n_write_available(0);
            uint32_t write_len = (available < tx_remain) ? available : (uint32_t)tx_remain;
            uint32_t written = 0;
            if (write_len > 0) written = tud_cdc_write(&cdc_tx.queue[tx_index].buf[tx_offset], write_len);

            mutex_enter_blocking(&cdc_output_mutex);
            if (cdc_tx.active && cdc_tx.read_index == tx_index &&
                cdc_tx.queue[tx_index].state == CDC_MSG_SENDING) {
                cdc_tx.offset += written;
            }
            if (cdc_tx.active && cdc_tx.offset == cdc_tx.length) {
                tud_cdc_write_flush();               // キュー1件の末尾でのみflush
                cdc_tx.queue[cdc_tx.read_index].state = CDC_MSG_FREE;
                cdc_tx.read_index = (cdc_tx.read_index + 1) % CDC_PRINTF_QSIZE;
                cdc_tx.count--;
                cdc_tx.active = false;
                cdc_tx.length = 0;
                cdc_tx.offset = 0;
            }
            mutex_exit(&cdc_output_mutex);
        }
    }

}

// callback when data is received on a CDC interface

void tud_cdc_line_state_cb(uint8_t itf, bool dtr, bool rts)
{
    printf("Set CDC Parameter...\n");
    displayFlag = true;
    crlfFlag = false;         // CR/LF 判定フラグ (BRCV 用)

}

void tud_umount_cb(void) {
    cdc_queue_reset();        // USB切断時は未送信データと送信中状態を破棄
}

void tud_cdc_send_break_cb(uint8_t itf, uint16_t wValue) {

    //Break信号が来た場合はCDC Queを空にします。
    printf("Breaked CDC...\n");
    displayFlag = true;
    cdc_queue_reset();

}


void tud_cdc_rx_cb(uint8_t itf)
{
    static int startAddress;                          // BRCV 受信開始アドレス
    static int length;                                // BRCV 残り長
    static bool bcvCmd = false;                       // BRCV 受信モードフラグ
    static bool bcvFail = false;                      // BRCV チェック失敗フラグ
    static char pendingLineEnd = 0;                   // BRCV直後に残る2文字目の改行コード
    uint32_t len = tud_cdc_read(rx_buf, RX_BUF_SIZE-1); // CDC からデータ読み出し
    char c;

    for (uint32_t i = 0; i < len; ++i) {

        if (bcvCmd == true){
            if (pendingLineEnd != 0) {
                char expected = pendingLineEnd;
                pendingLineEnd = 0;
                if (rx_buf[i] == (uint8_t)expected) continue;
            }
            uint32_t copy_len = len - i;
            if (copy_len > (uint32_t)length) copy_len = (uint32_t)length;
            memcpy(&slotMem[startAddress], &rx_buf[i], copy_len);
            startAddress += copy_len;
            length -= copy_len;
            i += copy_len - 1;
            if (length==0){
                mutex_enter_blocking(&cmdcount_mutex);
                commandBufs[write_idx].arg_val[1] = 0;
                commandBufs[write_idx].valid = true;   // 受信完了 => コマンドを有効化
                write_idx = (write_idx + 1) % CMD_BUF_NUM; // 次の書き込み位置へ
                count++;                                // キュー件数インクリメント
                mutex_exit(&cmdcount_mutex);
                bcvCmd = false;                         // BRCV モード終了
#ifdef BIN_DEBUG
                if (comdbgFlag)
                    printf("BIN End\n");       // デバッグ表示
#endif
            }
        }else{

            char c = toupper(rx_buf[i]);                   // 受信文字を大文字化 (コマンドは大文字前提)
#ifdef BIN_DEBUG
            if (comdbgFlag)
            //for Debug
                printf("%c",c);                            // 受信文字をデバッグ出力
#endif
 
            // 改行トリガー
            if ((uint8_t)c == ASCII_LF || (uint8_t)c == ASCII_CR) {
                
                if (lineLen == 0) crlfFlag = true;      // このFlagが立つ場合は改行は2Byte (CRLF 対策)

                if (lineLen > 0) {                      // 行バッファに何か入っていればパース開始
                    lineBuf[lineLen] = '\0';           // NUL 終端
                    // パースしてキューに格納
                    char tmpCmd[MAX_STRING] = {0};     // 一時 CMD 保持
                    char tmpArg[MAX_STRING] = {0};     // 一時 Arg 保持
                    char tmpData[MAX_STRING] = {0};    // tmpData (元コードの用途に合わせる)
                    int tmp_arg_val[MAX_ARG];          // 第2,3,4,5 の 16 進変換結果

                    for (uint j = 0; j< MAX_ARG;j++){
                        tmp_arg_val[j] = -1;          // 格納BUFFER初期化 // -1 は未指定
                    }

                    int idx=0;
                    char* token = strtok(lineBuf, ","); // カンマ区切り

                    if (token == NULL)  strncpy(tmpCmd, lineBuf, MAX_STRING-1);   // 第1パラのみの特例処理
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

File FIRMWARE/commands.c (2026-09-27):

#include "commands.h"

/*
 * コマンドリスト (元の cmd_table をここに移動)
 * 実際のコマンド処理関数 (cmd_slotReadMem 等) は main.c に残しています。
 * ここは名前と関数ポインタのマッピングのみを行うファイルです。
 */

//// Support Command ////////////////////////////////////////////////////////////////////////////////////////////////////////////////////////////////////////////////////////////////////////////
// BUFFER Clear                	BCLR	cmd_bufClear        	BCLR(, [Buffer Address],[Length],[Data])          	戻値: OK                      	Buffer RAMのClear
// BUFFER Receive Host         	BRCV	cmd_host2buf        	BRCV,[Buffer Address],[Length]                  	戻値: バイナリーデータ           Buffer RAMからHOSTへのデータ転送
// BUFFER Send Host            	BSND	cmd_buf2Host        	BSND,[Buffer Address],[Length]                  	戻値: OK                    	Buffer RAMへのHOSTからのデータ転送
// HW Version                  	HVER	cmd_hwVersion       	HVER                                            	戻値: Hardware Version + OK   	Hardware Version
// HW information              	HINF	cmd_hwInfomation    	HINF                                            	戻値: Hardware 情報   + OK    	Hardware Information
// HW setting                  	HSET	cmd_hwSetting       	HSET,[Address],[Data]                           	戻値: OK                      	Hardware Setting
// HW Status                   	HSTS	cmd_hwIntenalStatus 	HSTS                                            	戻値: 内部STATUS  + OK        	SlotのCMD実行状態を表示
// Slot Check                  	SCHK	cmd_slotCassetteCheck	SCHK                                            	戻値: SLT1/2の接続状態 +OK    	SlotのCassette接続状態を表示(Power ON不要)
// Slot Power ON               	SPON	cmd_slotPowerOn      	SPON                                            	戻値: OK                      	Slotの電源を入れて、状態のセルフチェック,各信号の有効化,RESETをします。
// Slot Power OFF              	SPOFF	cmd_slotPowerOff    	SPOFF                                           	戻値: OK                      	Slotの電源をOFFにします。
// Slot Mem Read               	SMRD	cmd_slotReadMem     	SMRD,[Address](,[Slot])                         	戻値: Read値（ASCII16進) +OK  	Slotから1Byte Readします
// Slot Mem Write              	SMWR	cmd_slotWriteMem    	SMRD,[Address],[Data](,[Slot])                  	戻値: OK                      	Slotへ1Byte Writeします
// Slot Mem Transfer Read      	SMTR	cmd_slotReadTransfer	SMTR,[Address](,[Length],[Buffer Address],[Slot])	戻値: なし                    	SlotからBufferへ一括Readします
// Slot Mem Transfer Write     	SMTW	cmd_slotWriteTransfer	SMTW,[Address],[Length],[Buffer Address](,[Slot])	戻値: なし                    	BufferからSlotへ一括Writeします
// Slot Select                 	SSEL	cmd_slotSelect      	SSEL,[Slot]                                     	戻値: なし                    	Slot選択
// Slot Reset                  	SRST	cmd_slotReset       	SRST                                            	戻値: OK                      	SlotのReset
// IO Read                     	IORD	cmd_ioRead          	IORD,[IO]                                       	戻値: Read値 + OK             	IOへ1Byte Readします
// IO Write                    	IOWR	cmd_ioWrite         	IOWR,[IO],[Data]                                	戻値: OK                      	IOから1Byte Writeします
// IO Transfer Read            	IOTR	cmd_buf2io          	IOTR,[IO],[Length],[Buffer Address]               	戻値: なし                    	IOへBufferへ一括Readします
// IO Transfer Write           	IOTW	cmd_io2buf          	IOTW,[Buffer Address],[Length],[IO]               	戻値: なし                    	BufferからIOへ一括Writeします
// BUFFER Dump                 	BDMP	cmd_bufDump         	BDMP,[Buffer Address],([Length] )                   戻値: 128Byte DUMP値 +OK      	Bufferのデータ内容の表示(DEBUG用)
// Slot Dump                 	SDMP	cmd_slotDump         	SDMP,[Buffer Address],([Length],[Slot])             戻値: 128Byte DUMP値 +OK      	Bufferのデータ内容の表示(DEBUG用)
// Move2Bootloader Mode    	    _FFU	cmd_ffuMode        	    _FFU            	                                戻値: 無し       	            Bootloaderを起動します。
// Result OFF               	ERROFF	cmd_err_displayOff     	ERROFF                                    	        戻値: 無し                      DISPON　CMD後のOK表示無し
// Result ON               	    ERRON	cmd_err_displayOn     	ERRON                                       	    戻値: ERROFF中の結果            DISPON　CMD後のOK表示の再表示
// LED Color(RDY)               LEDRDY   cmd_ledColorReady      LEDRDY,[R],[G],[B]                                   戻値: 無し                      LEDの色変更(Ready)
// LED Color(PON)               LEDPON   cmd_ledColorPowerOn    LEDPON,[R],[G],[B]                                   戻値: 無し                      LEDの色変更(PowerON)
// LED Color(ACC)               LEDACC   cmd_ledColorAcc        LEDACC,[R],[G],[B]                                   戻値: 無し                      LEDの色変更(Access)

extern int null_format(const Command_t* cmd);           // main.c 実装
extern int cmd_err_displayOff(const Command_t* cmd);    // main.c 実装
extern int cmd_err_displayOn(const Command_t* cmd);     // main.c 実装
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

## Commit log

2026-04-24 Initial commit: Add project structure and documentation
    Initial commit with project documentation
    This commit introduces:
    - Project README with overview and features
    - License file (MIT)
    - Initial project structure
    [MSXPLAYerCR_RevE - Bottom Copper (Resist).gbr, MSXPLAYerCR_RevE - Bottom Copper.gbr, MSXPLAYerCR_RevE - Drill Ident Drawing - [Through Hole].gbr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]
2026-05-07 update READMEs
    Update readme.md and readme_en.md to use the fixed title images, embed the PCB photo, and replace the Booth preparation note with the actual Booth URL.
2026-05-12 Add cartridge detection and power control functions
2026-05-13 Revert "Add cartridge detection and power control functions"
    This reverts commit 4318a4b44106579b7a83538718c8b19ac4c96dd7.
2026-05-13 Use 0x9000 slot address for KONAMI SCC
    Fix incorrect slot write address in ReadKONAMI_SCC: change slotWrite call from 0x8000 to 0x9000 to select the proper bank before dumping SCC data. Updated x64 Release executable accordingly.
2026-05-19 Add SMTH command, PUSH op and New ROM dumper tool(using SMTH)
    Register new SMTH command and implement slot read+hash transfer (cmd_slotReadTransferWithHash) in firmware; add PUSH script opcode to write lastData to slot buffer.
2026-05-24 Add HSET timing control & ROM dumper enhancements
    Firmware: add HSET command to adjust memory access timings (MEMWAIT, RDWAIT, WRWAIT) and enable PC6001 16KB mode; apply timing and slot-selection fixes for PCB variants, extend RD/WR/memory wait handling, and expose these settings via hw info. Update UF2 and ffu.bat to new build.
    Software: enhance MSXCR_ROMDUMPER with utility helpers, UTF/UTF‑8 path handling, SHA-1 calculation, XML DB lookup (search ROM info by SHA1), SlotReset and hardwareSetting commands, read-timing sweep/check routines to stabilize hashes, and improved mapper detection including SRAM checks. Also include updated Windows binaries.
    [commands.c, main.c]
2026-05-24 Fix IO mask bit in slotWriteIO
    Change io_mask shift from 4 to 3 in main.c (slotWriteIO) to correct the IO bit mapping (was targeting the wrong IO line). Updated UF2 firmware binary included to reflect the rebuild with this fix.
    [main.c]
2026-05-27 BS6101 fixes and hash/detection improvements
    Firmware: Change RD/WR signals to push-pull for BS6101 ASCII3 ROM workarounds (add WR/RD masks, set OE, adjust release timing).
    Software: MSXCR_ROMDUMPER.cpp - change HASH_SIZE to 0x1000, add HashFilledFF helper and replace hardcoded magic-hash checks with filledFF comparisons, reduce sweep timing range.
    [main.c]
2026-05-30 HVER : YYYYMMDD
    Switched to a script-based update for the BUILD_DATE macro definition file on every build.
2026-09-27 Add REV_F support and harden USB CDC
    Adds RP2354B board support with Pico SDK 2.3.0, TinyUSB 0.21.0, and a local TinyUSB recovery patch. Adds REV_F buffer/clock handling
    It also reworks CDC transmit queuing and BRCV line-ending handling to improve reliability during heavy USB transfers.
    [ILF_RP2354B_MSXREADER.h, commands.c, factory_test_b2.c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]
